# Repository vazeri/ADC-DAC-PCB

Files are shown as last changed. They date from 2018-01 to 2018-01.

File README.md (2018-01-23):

# Tarjeta para procesamiento de audio Analógico/Digital

Este proyecto se encuentra documentado y explicado a profundidad en el siguiente [articulo](https://github.com/vazeri/ADC-DAC-PCB/blob/master/pdf/ArticuloDAC.pdf)
 
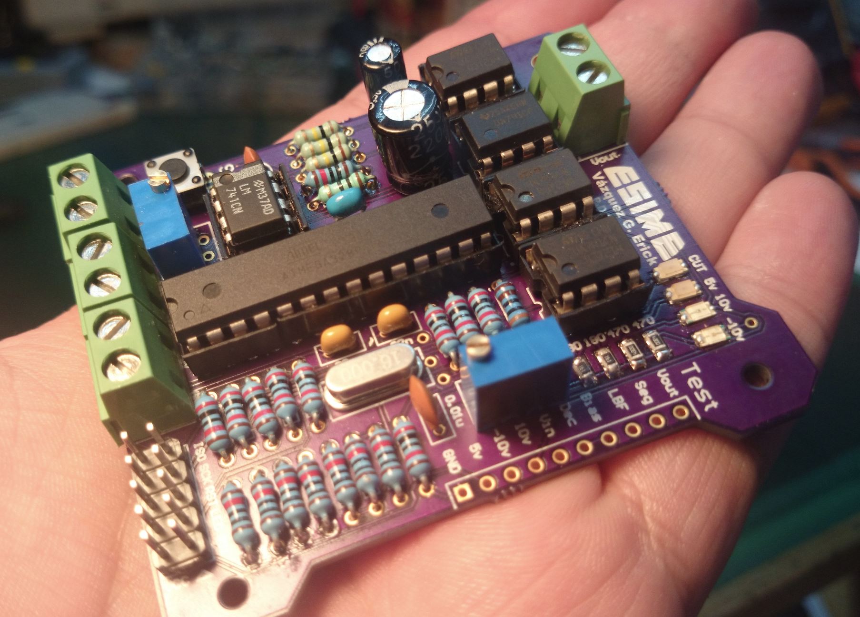
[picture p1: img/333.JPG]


El sonido y la computadora son inseparables, hoy en día en pocas aplicaciones se trabaja audio analógico y
casi todas editan por medio de software digitalmente, pero el sonido, en su origen continua siendo analógico...

La computadora, por lo tanto, tiene que contar con un dispositivo que transforme el audio analógico en digital
a este se llama tarjeta de audio de sonido que usualmente contiene un convertidor Analógico-Digital y un convertidor Digital-Analógico. En este reporte se describe el proceso de digitalizar una señal analógica de la voz humana, así como la serie de pasos a seguir para revertir este proceso

# ¿El proceso?



Es necesario tener un poco de teoría para comprender el proceso de el desarrollo teórico, esquemático y de PCB, para la implementación de una tarjeta de audio utilizando un microcontrolador de 8 bits ATMEGA328p

Los temas recomendados a estudiar antes de entrar de lleno a este proyecto son 

* Teorema de Nyquist
* Filtros de corriente directa
* Corrimientos de corriente directa
* Convertidor Analógico-Digital
* Arreglos Digital-Analógico R/2R 
* Filtros Pasa bajas
* Seguidor de tensión

En la carpeta PDF se anexan dos artículos en PDF para profundizar un poco sobre el tema, así como un [articulo](https://github.com/vazeri/ADC-DAC-PCB/blob/master/pdf/ArticuloDAC.pdf) escrito por mí para detallar el proceso de implementación del mismo 

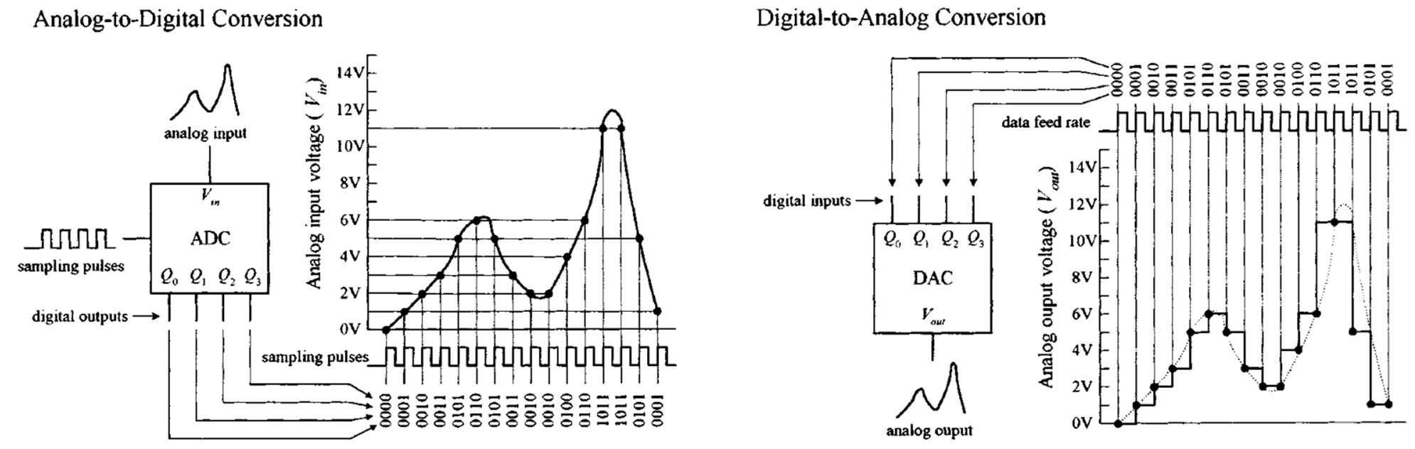
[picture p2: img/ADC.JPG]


# Esquemático

El esquemático fue diseñado el Altium Designer 14, en su versión de prueba, y se usa solo con fines educativos, 

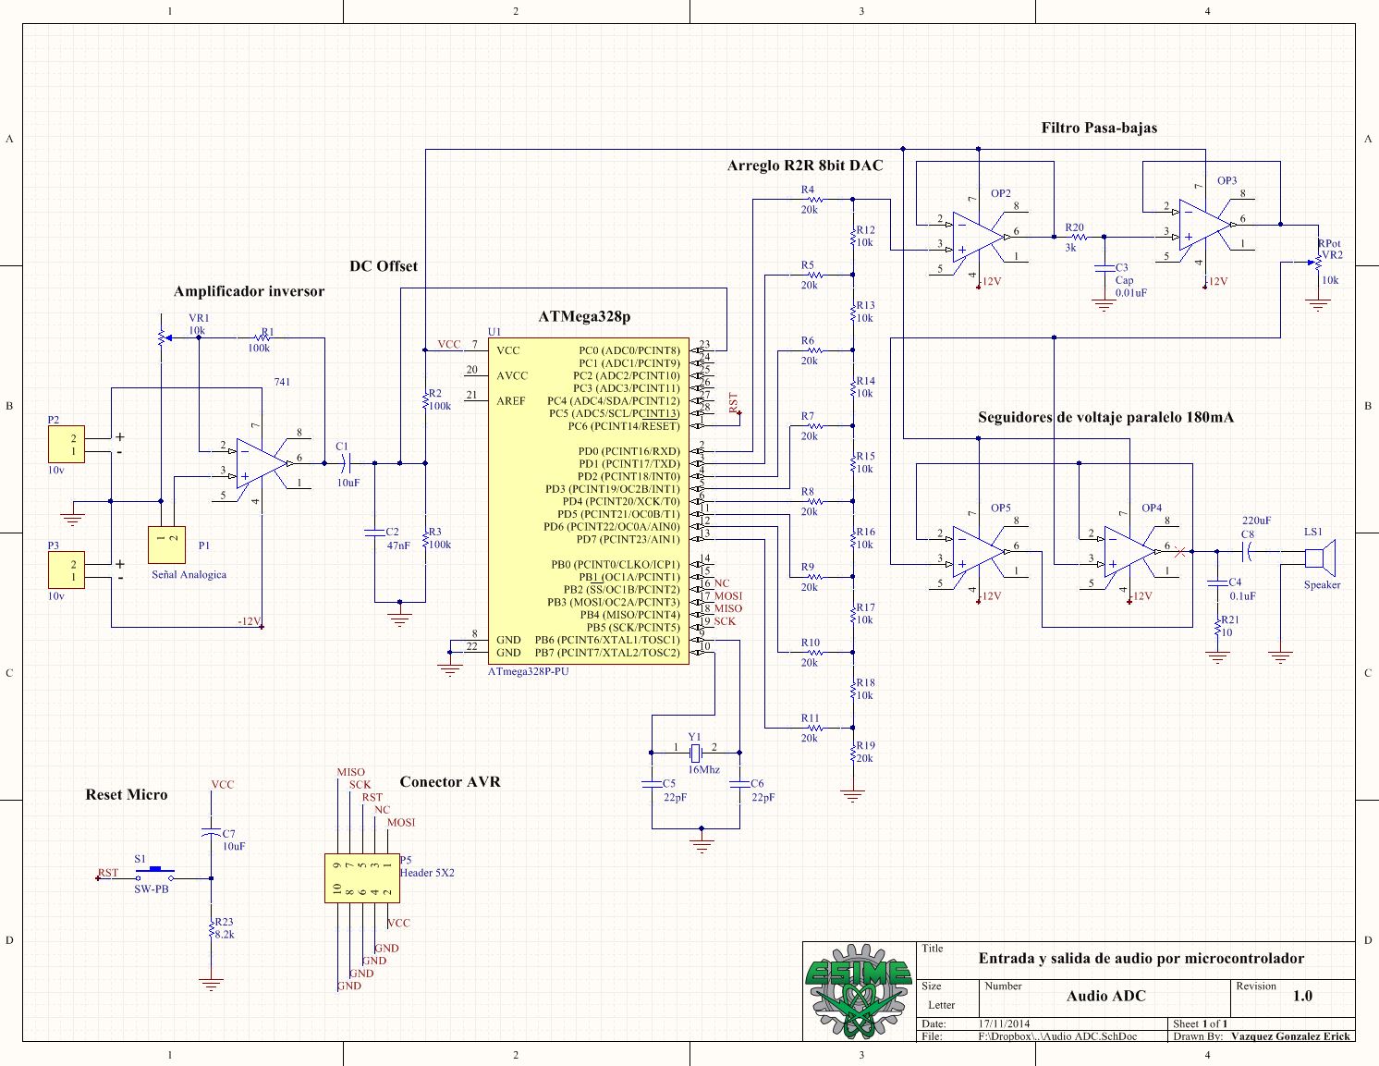
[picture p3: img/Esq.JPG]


# Placa de Circuito Impreso

El PCB de dos capas fue maquilado utilizando OSHPark con acabados ENIG oro

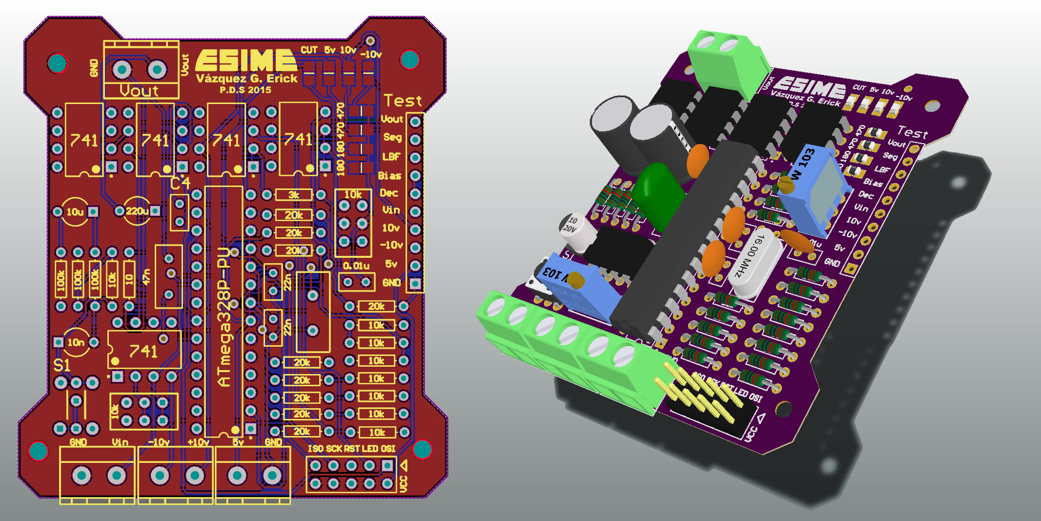
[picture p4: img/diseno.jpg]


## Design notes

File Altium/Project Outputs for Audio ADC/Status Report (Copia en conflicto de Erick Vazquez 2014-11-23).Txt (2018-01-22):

Output: NC Drill Files
Type  : NC Drill
From  : Project [Audio ADC.PrjPcb]
   Generated File[Audio ADC-RoundHoles.TXT]
   Generated File[Audio ADC-SquareHoles.TXT]
   Generated File[Audio ADC.DRL]
   Generated File[Audio ADC.LDP]
   Generated File[Audio ADC.DRR]

Files Generated   : 5
Documents Printed : 0

Finished Output Generation At 01:49:13 a.m. On 23/11/2014

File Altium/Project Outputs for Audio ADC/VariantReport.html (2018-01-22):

Altium customize

# Variant Report

Date | : | 07/11/2014
Time | : | 09:32:15 a.m.
Elapsed Time | : | 00:00:00

## Variations

Physical | Document | Parameter Name | Original Value
C1 | Audio ADC.SchDoc | | Fitted
| | Comment | Cap2
| | Description | Capacitor
| | Footprint | RAD-0.1
| | PackageDescription | Capacitor; 2 Leads
| | PackageReference | CAPR5-4X5
| | Published | 23-Sep-2002
| | Publisher | Altium Limited
| | Value | 10uF
C2 | Audio ADC.SchDoc | | Fitted
| | Comment | Cap
| | Description | Capacitor
| | Footprint | RAD-0.1
| | LatestRevisionDate | 17-Jul-2002
| | LatestRevisionNote | Re-released for DXP Platform.
| | PackageDescription | Radial Cap, Thru-Hole; 2 Leads; 0.3 in Pin Spacing
| | PackageReference | RAD-0.3
| | Published | 8-Jun-2000
| | Publisher | Altium Limited
| | Value | 47nF
C3 | Audio ADC.SchDoc | | Fitted
| | Comment | Cap
| | Description | Capacitor
| | Footprint | RAD-0.3
| | LatestRevisionDate | 17-Jul-2002
| | LatestRevisionNote | Re-released for DXP Platform.
| | PackageDescription | Radial Cap, Thru-Hole; 2 Leads; 0.3 in Pin Spacing
| | PackageReference | RAD-0.3
| | Published | 8-Jun-2000
| | Publisher | Altium Limited
| | Value | 0.01uF
C4 | Audio ADC.SchDoc | | Fitted
| | Comment | Cap
| | Description | Capacitor
| | Footprint | RAD-0.1
| | LatestRevisionDate | 17-Jul-2002
| | LatestRevisionNote | Re-released for DXP Platform.
| | PackageDescription | Radial Cap, Thru-Hole; 2 Leads; 0.3 in Pin Spacing
| | PackageReference | RAD-0.3
| | Published | 8-Jun-2000
| | Publisher | Altium Limited
| | Value | 0.1uF
C5 | Audio ADC.SchDoc | | Fitted
| | Comment | Cap
| | Description | Capacitor
| | Footprint | RAD-0.1
| | LatestRevisionDate | 17-Jul-2002
| | LatestRevisionNote | Re-released for DXP Platform.
| | PackageDescription | Radial Cap, Thru-Hole; 2 Leads; 0.3 in Pin Spacing
| | PackageReference | RAD-0.3
| | Published | 8-Jun-2000
| | Publisher | Altium Limited
| | Value | 22pF
C6 | Audio ADC.SchDoc | | Fitted
| | Comment | Cap
| | Description | Capacitor
| | Footprint | RAD-0.1
| | LatestRevisionDate | 17-Jul-2002
| | LatestRevisionNote | Re-released for DXP Platform.
| | PackageDescription | Radial Cap, Thru-Hole; 2 Leads; 0.3 in Pin Spacing
| | PackageReference | RAD-0.3
| | Published | 8-Jun-2000
| | Publisher | Altium Limited
| | Value | 22pF
C7 | Audio ADC.SchDoc | | Fitted
| | Comment | Cap2
| | Description | Capacitor
| | Footprint | CAPR5-4X5
| | PackageDescription | Capacitor; 2 Leads
| | PackageReference | CAPR5-4X5
| | Published | 23-Sep-2002
| | Publisher | Altium Limited
| | Value | 10uF
C8 | Audio ADC.SchDoc | | Fitted
| | Comment | Cap2
| | Description | Capacitor
| | Footprint | CAPR5-4X5
| | PackageDescription | Capacitor; 2 Leads
| | PackageReference | CAPR5-4X5
| | Published | 23-Sep-2002
| | Publisher | Altium Limited
| | Value | 220uF
LS1 | Audio ADC.SchDoc | | Fitted
| | Comment | Speaker
| | Description | Loudspeaker
| | Footprint | cONECTOR
| | LatestRevisionDate | 17-Jul-2002
| | LatestRevisionNote | Re-released for DXP Platform.
| | PackageReference | PIN2
| | Published | 24-Mar-1999
| | Publisher | Altium Limited
OP1 | Audio ADC.SchDoc | | Fitted
| | Comment | 741
| | ComponentLink1Description | Manufacturer Link
| | ComponentLink1URL | http://www.analog.com/
| | DatasheetVersion | REV. B
| | Description | FET Operational Amplifier
| | Footprint | DIP-8
| | LatestRevisionDate | 17-Jul-2002
| | LatestRevisionNote | Re-released for DXP Platform.
| | PackageDescription | Can; 8 Leads; Pin Circle Dia. 5.08 mm; Lead Dia. 0.53 mm (max)
| | PackageReference | H-08A
| | PackageVersion | 1990
| | Published | 8-Jun-2000
| | Publisher | Altium Limited
OP2 | Audio ADC.SchDoc | | Fitted
| | Comment | Op Amp
| | ComponentLink1Description | Manufacturer Link
| | ComponentLink1URL | http://www.analog.com/
| | DatasheetVersion | REV. B
| | Description | FET Operational Amplifier
| | Footprint | DIP-8
| | LatestRevisionDate | 17-Jul-2002
| | LatestRevisionNote | Re-released for DXP Platform.
| | PackageDescription | Can; 8 Leads; Pin Circle Dia. 5.08 mm; Lead Dia. 0.53 mm (max)
| | PackageReference | H-08A
| | PackageVersion | 1990
| | Published | 8-Jun-2000
| | Publisher | Altium Limited
OP3 | Audio ADC.SchDoc | | Fitted
| | Comment | Op Amp
| | ComponentLink1Description | Manufacturer Link
| | ComponentLink1URL | http://www.analog.com/
| | DatasheetVersion | REV. B
| | Description | FET Operational Amplifier
| | Footprint | DIP-8
| | LatestRevisionDate | 17-Jul-2002
| | LatestRevisionNote | Re-released for DXP Platform.
| | PackageDescription | Can; 8 Leads; Pin Circle Dia. 5.08 mm; Lead Dia. 0.53 mm (max)
| | PackageReference | H-08A
| | PackageVersion | 1990
| | Published | 8-Jun-2000
| | Publisher | Altium Limited
OP4 | Audio ADC.SchDoc | | Fitted
| | Comment | Op Amp
| | ComponentLink1Description | Manufacturer Link
| | ComponentLink1URL | http://www.analog.com/
| | DatasheetVersion | REV. B
| | Description | FET Operational Amplifier
| | Footprint | DIP-8
| | LatestRevisionDate | 17-Jul-2002
| | LatestRevisionNote | Re-released for DXP Platform.
| | PackageDescription | Can; 8 Leads; Pin Circle Dia. 5.08 mm; Lead Dia. 0.53 mm (max)
| | PackageReference | H-08A
| | PackageVersion | 1990
| | Published | 8-Jun-2000
| | Publisher | Altium Limited
OP5 | Audio ADC.SchDoc | | Fitted
| | Comment | Op Amp
| | ComponentLink1Description | Manufacturer Link
| | ComponentLink1URL | http://www.analog.com/
| | DatasheetVersion | REV. B
| | Description | FET Operational Amplifier
| | Footprint | DIP-8
| | LatestRevisionDate | 17-Jul-2002
| | LatestRevisionNote | Re-released for DXP Platform.
| | PackageDescription | Can; 8 Leads; Pin Circle Dia. 5.08 mm; Lead Dia. 0.53 mm (max)
| | PackageReference | H-08A
| | PackageVersion | 1990
| | Published | 8-Jun-2000
| | Publisher | Altium Limited
P1 | Audio ADC.SchDoc | | Fitted
| | Comment | Señal Analogica
| | Description | Header, 2-Pin
| | Footprint | cONECTOR
| | LatestRevisionDate | 17-Jul-2002
| | LatestRevisionNote | Re-released for DXP Platform.
| | Publisher | Altium Limited
P2 | Audio ADC.SchDoc | | Fitted
| | Comment | 12v
| | Description | Header, 2-Pin
| | Footprint | cONECTOR
| | LatestRevisionDate | 17-Jul-2002
| | LatestRevisionNote | Re-released for DXP Platform.
| | Publisher | Altium Limited
P3 | Audio ADC.SchDoc | | Fitted
| | Comment | 12v
| | Description | Header, 2-Pin
| | Footprint | MHDR1X2
| | LatestRevisionDate | 17-Jul-2002
| | LatestRevisionNote | Re-released for DXP Platform.
| | Publisher | Altium Limited
P5 | Audio ADC.SchDoc | | Fitted
| | Comment | Header 5X2
| | Description | Header, 5-Pin, Dual row
| | Footprint | HDR2X5
| | LatestRevisionDate | 17-Jul-2002
| | LatestRevisionNote | Re-released for DXP Platform.
| | Publisher | Altium Limited
R1 | Audio ADC.SchDoc | | Fitted
| | 100k | 100k
| | Comment | 100k
| | Description | Resistor
| | Footprint | AXIAL-0.3
| | LatestRevisionDate | 17-Jul-2002
| | LatestRevisionNote | Re-released for DXP Platform.
| | PackageDescription | Axial Device, Thru-Hole; 2 Leads; 0.3 in Pin Spacing
| | PackageReference | AXIAL-0.3
| | Published | 8-Jun-2000
| | Publisher | Altium Limited
R2 | Audio ADC.SchDoc | | Fitted
| | Comment | 100k
| | Description | Resistor
| | Footprint | AXIAL-0.3
| | LatestRevisionDate | 17-Jul-2002
| | LatestRevisionNote | Re-released for DXP Platform.
| | PackageDescription | Axial Device, Thru-Hole; 2 Leads; 0.3 in Pin Spacing
| | PackageReference | AXIAL-0.3
| | Published | 8-Jun-2000
| | Publisher | Altium Limited
| | Value | 100k
R3 | Audio ADC.SchDoc | | Fitted
| | Comment | 100k
| | Description | Resistor
| | Footprint | AXIAL-0.3
| | LatestRevisionDate | 17-Jul-2002
| | LatestRevisionNote | Re-released for DXP Platform.
| | PackageDescription | Axial Device, Thru-Hole; 2 Leads; 0.3 in Pin Spacing
| | PackageReference | AXIAL-0.3
| | Published | 8-Jun-2000
| | Publisher | Altium Limited
| | Value | 100k
R4 | Audio ADC.SchDoc | | Fitted
| | Comment | 20k
| | Description | Resistor
| | Footprint | AXIAL-0.3
| | LatestRevisionDate | 17-Jul-2002
| | LatestRevisionNote | Re-released for DXP Platform.
| | PackageDescription | Axial Device, Thru-Hole; 2 Leads; 0.3 in Pin Spacing
| | PackageReference | AXIAL-0.3
| | Published | 8-Jun-2000
| | Publisher | Altium Limited
| | Value | 1K
R5 | Audio ADC.SchDoc | | Fitted
| | Comment | 20k
| | Description | Resistor
| | Footprint | AXIAL-0.3
| | LatestRevisionDate | 17-Jul-2002
| | LatestRevisionNote | Re-released for DXP Platform.
| | PackageDescription | Axial Device, Thru-Hole; 2 Leads; 0.3 in Pin Spacing
| | PackageReference | AXIAL-0.3
| | Published | 8-Jun-2000
| | Publisher | Altium Limited
| | Value | 1K
R6 | Audio ADC.SchDoc | | Fitted
| | Comment | 20k
| | Description | Resistor
| | Footprint | AXIAL-0.3
| | LatestRevisionDate | 17-Jul-2002
| | LatestRevisionNote | Re-released for DXP Platform.
| | PackageDescription | Axial Device, Thru-Hole; 2 Leads; 0.3 in Pin Spacing
| | PackageReference | AXIAL-0.3
| | Published | 8-Jun-2000
| | Publisher | Altium Limited
| | Value | 1K
R7 | Audio ADC.SchDoc | | Fitted
| | Comment | 20k
| | Description | Resistor
| | Footprint | AXIAL-0.3
| | LatestRevisionDate | 17-Jul-2002
| | LatestRevisionNote | Re-released for DXP Platform.
| | PackageDescription | Axial Device, Thru-Hole; 2 Leads; 0.3 in Pin Spacing
| | PackageReference | AXIAL-0.3
| | Published | 8-Jun-2000
| | Publisher | Altium Limited
| | Value | 1K
R8 | Audio ADC.SchDoc | | Fitted
| | Comment | 20k
| | Description | Resistor
| | Footprint | AXIAL-0.3
| | LatestRevisionDate | 17-Jul-2002
| | LatestRevisionNote | Re-released for DXP Platform.
| | PackageDescription | Axial Device, Thru-Hole; 2 Leads; 0.3 in Pin Spacing
| | PackageReference | AXIAL-0.3
| | Published | 8-Jun-2000
| | Publisher | Altium Limited
| | Value | 1K
R9 | Audio ADC.SchDoc | | Fitted
| | Comment | 20k
| | Description | Resistor
| | Footprint | AXIAL-0.3
| | LatestRevisionDate | 17-Jul-2002
| | LatestRevisionNote | Re-released for DXP Platform.
| | PackageDescription | Axial Device, Thru-Hole; 2 Leads; 0.3 in Pin Spacing
| | PackageReference | AXIAL-0.3
| | Published | 8-Jun-2000
| | Publisher | Altium Limited
| | Value | 1K
R10 | Audio ADC.SchDoc | | Fitted
| | Comment | 20k
| | Description | Resistor
| | Footprint | AXIAL-0.3
| | LatestRevisionDate | 17-Jul-2002
| | LatestRevisionNote | Re-released for DXP Platform.
| | PackageDescription | Axial Device, Thru-Hole; 2 Leads; 0.3 in Pin Spacing
| | PackageReference | AXIAL-0.3
| | Published | 8-Jun-2000
| | Publisher | Altium Limited
| | Value | 1K
R11 | Audio ADC.SchDoc | | Fitted
| | Comment | 20k
| | Description | Resistor
| | Footprint | AXIAL-0.3
| | LatestRevisionDate | 17-Jul-2002
| | LatestRevisionNote | Re-released for DXP Platform.
| | PackageDescription | Axial Device, Thru-Hole; 2 Leads; 0.3 in Pin Spacing
| | PackageReference | AXIAL-0.3
| | Published | 8-Jun-2000
| | Publisher | Altium Limited
| | Value | 1K
R12 | Audio ADC.SchDoc | | Fitted
| | Comment | 10k
| | Description | Resistor
| | Footprint | AXIAL-0.3
| | LatestRevisionDate | 17-Jul-2002
| | LatestRevisionNote | Re-released for DXP Platform.
| | PackageDescription | Axial Device, Thru-Hole; 2 Leads; 0.3 in Pin Spacing
| | PackageReference | AXIAL-0.3
| | Published | 8-Jun-2000
| | Publisher | Altium Limited
| | Value | 1K
R13 | Audio ADC.SchDoc | | Fitted
| | Comment | 10k
| | Description | Resistor
| | Footprint | AXIAL-0.3
| | LatestRevisionDate | 17-Jul-2002
| | LatestRevisionNote | Re-released for DXP Platform.
| | PackageDescription | Axial Device, Thru-Hole; 2 Leads; 0.3 in Pin Spacing
| | PackageReference | AXIAL-0.3
| | Published | 8-Jun-2000
| | Publisher | Altium Limited
| | Value | 1K
R14 | Audio ADC.SchDoc | | Fitted
| | Comment | 10k
| | Description | Resistor
| | Footprint | AXIAL-0.3
| | LatestRevisionDate | 17-Jul-2002
| | LatestRevisionNote | Re-released for DXP Platform.
| | PackageDescription | Axial Device, Thru-Hole; 2 Leads; 0.3 in Pin Spacing
| | PackageReference | AXIAL-0.3
| | Published | 8-Jun-2000
| | Publisher | Altium Limited
| | Value | 1K
R15 | Audio ADC.SchDoc | | Fitted
| | Comment | 10k
| | Description | Resistor
| | Footprint | AXIAL-0.3
| | LatestRevisionDate | 17-Jul-2002
| | LatestRevisionNote | Re-released for DXP Platform.
| | PackageDescription | Axial Device, Thru-Hole; 2 Leads; 0.3 in Pin Spacing
| | PackageReference | AXIAL-0.3
| | Published | 8-Jun-2000
| | Publisher | Altium Limited
| | Value | 1K
R16 | Audio ADC.SchDoc | | Fitted
| | Comment | 10k
| | Description | Resistor
| | Footprint | AXIAL-0.3
| | LatestRevisionDate | 17-Jul-2002
| | LatestRevisionNote | Re-released for DXP Platform.
| | PackageDescription | Axial Device, Thru-Hole; 2 Leads; 0.3 in Pin Spacing
| | PackageReference | AXIAL-0.3
| | Published | 8-Jun-2000
| | Publisher | Altium Limited
| | Value | 1K
R17 | Audio ADC.SchDoc | | Fitted
| | Comment | 10k
| | Description | Resistor
| | Footprint | AXIAL-0.3
| | LatestRevisionDate | 17-Jul-2002
| | LatestRevisionNote | Re-released for DXP Platform.
| | PackageDescription | Axial Device, Thru-Hole; 2 Leads; 0.3 in Pin Spacing
| | PackageReference | AXIAL-0.3
| | Published | 8-Jun-2000
| | Publisher | Altium Limited
| | Value | 1K
R18 | Audio ADC.SchDoc | | Fitted
| | Comment | 10k
| | Description | Resistor
| | Footprint | AXIAL-0.3
| | LatestRevisionDate | 17-Jul-2002
| | LatestRevisionNote | Re-released for DXP Platform.
| | PackageDescription | Axial Device, Thru-Hole; 2 Leads; 0.3 in Pin Spacing
| | PackageReference | AXIAL-0.3
| | Published | 8-Jun-2000
| | Publisher | Altium Limited
| | Value | 1K
R19 | Audio ADC.SchDoc | | Fitted
| | Comment | 20k
| | Description | Resistor
| | Footprint | AXIAL-0.3
| | LatestRevisionDate | 17-Jul-2002
| | LatestRevisionNote | Re-released for DXP Platform.
| | PackageDescription | Axial Device, Thru-Hole; 2 Leads; 0.3 in Pin Spacing
| | PackageReference | AXIAL-0.3
| | Published | 8-Jun-2000
| | Publisher | Altium Limited
| | Value | 1K
R20 | Audio ADC.SchDoc | | Fitted
| | Comment | 3k
| | Description | Resistor
| | Footprint | AXIAL-0.3
| | LatestRevisionDate | 17-Jul-2002
| | LatestRevisionNote | Re-released for DXP Platform.
| | PackageDescription | Axial Device, Thru-Hole; 2 Leads; 0.3 in Pin Spacing
| | PackageReference | AXIAL-0.3
| | Published | 8-Jun-2000
| | Publisher | Altium Limited
| | Value | 1K
R21 | Audio ADC.SchDoc | | Fitted
| | Comment | 10
| | Description | Resistor
| | Footprint | AXIAL-0.3
| | LatestRevisionDate | 17-Jul-2002
| | LatestRevisionNote | Re-released for DXP Platform.
| | PackageDescription | Axial Device, Thru-Hole; 2 Leads; 0.3 in Pin Spacing
| | PackageReference | AXIAL-0.3
| | Published | 8-Jun-2000
| | Publisher | Altium Limited
| | Value | 1K
R23 | Audio ADC.SchDoc | | Fitted
| | Comment | 8.2k
| | Description | Resistor
| | Footprint | AXIAL-0.3
| | LatestRevisionDate | 17-Jul-2002
| | LatestRevisionNote | Re-released for DXP Platform.
| | PackageDescription | Axial Device, Thru-Hole; 2 Leads; 0.3 in Pin Spacing
| | PackageReference | AXIAL-0.3
| | Published | 8-Jun-2000
| | Publisher | Altium Limited
| | Value | 1K
S1 | Audio ADC.SchDoc | | Fitted
| | Comment | SW-PB
| | Description | Switch
| | Footprint | SPST-2
| | LatestRevisionDate | 17-Jul-2002
| | LatestRevisionNote | Re-released for DXP Platform.
| | PackageDescription | Switch; 2 Leads
| | PackageReference | SPST-2
| | Published | 24-Mar-1999
| | Publisher | Altium Limited
U1 | Audio ADC.SchDoc | | Fitted
| | Comment | ATmega328P-PU
| | ComponentLink1Description | Manufacturer Link
| | ComponentLink1URL | http://www.atmel.com/products/avr/default.asp?
| | ComponentLink2Description | ATmega48A/48PA/88A/88PA/168A/168PA/328/328P Datasheet
| | ComponentLink2URL | http://www.atmel.com/dyn/resources/prod_documents/8271.pdf
| | ComponentLink3Description | ATmega48A/48PA/88A/88PA/168A/168PA/328/328P Summary
| | ComponentLink3URL | http://www.atmel.com/dyn/resources/prod_documents/8271S.pdf
| | ComponentLink4Description | Atmel.com Home
| | ComponentLink4URL | http://www.atmel.com
| | DatasheetVersion | revA, Jan-2010
| | Description | 8-bit AVR Microcontroller, 32KB Flash, 1KB EEPROM, 2KB SRAM, 28-pin PDIP, Industrial Grade (-40°C to 85°C)
| | Footprint | 28P3
| | PackageDescription | 28-lead (0.300"/7.62mm Wide) Plastic Dual Inline Package (PDIP)
| | PackageReference | 28P3
| | PackageVersion | revB, Sep-2001
| | Published | 1-Apr-2010
| | Publisher | Altium Limited
| | Supplier 1 | Digi-Key
| | Supplier 2 | Farnell
| | Supplier 3 | Mouser
| | Supplier Part Number 1 | ATMEGA328P-PU-ND
| | Supplier Part Number 2 | 1715487
| | Supplier Part Number 3 | 556-ATMEGA328P-PU
VR1 | Audio ADC.SchDoc | | Fitted
| | Comment | RPot
| | Description | Potentiometer
| | Footprint | VR5
| | LatestRevisionDate | 17-Jul-2002
| | LatestRevisionNote | Re-released for DXP Platform.
| | PackageDescription | Variable Resistor, Thru-Hole; 3 Leads
| | PackageReference | VR5
| | Published | 8-Jun-2000
| | Publisher | Altium Limited
| | Set Position | 0.5
| | Sim Note | Enter the Resistance value and the set point into parameter fields.
| | Value | 10k
VR2 | Audio ADC.SchDoc | | Fitted
| | Comment | RPot
| | Description | Potentiometer
| | Footprint | VR5
| | LatestRevisionDate | 17-Jul-2002
| | LatestRevisionNote | Re-released for DXP Platform.
| | PackageDescription | Variable Resistor, Thru-Hole; 3 Leads
| | PackageReference | VR5
| | Published | 8-Jun-2000
| | Publisher | Altium Limited
| | Set Position | 0.5
| | Sim Note | Enter the Resistance value and the set point into parameter fields.
| | Value | 10k
Y1 | Audio ADC.SchDoc | | Fitted
| | Comment | 16Mhz
| | Description | Crystal Oscillator
| | Footprint | RAD-0.4
| | LatestRevisionDate | 17-Jul-2002
| | LatestRevisionNote | Re-released for DXP Platform.
| | PackageDescription | Crystal, Thru-Hole; 2 Leads; Body 3.1 x 8.2 mm (Dia.xH)
| | PackageReference | R38
| | Published | 8-Jun-2000
| | Publisher | Altium Limited

Back to top

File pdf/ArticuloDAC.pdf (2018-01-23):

Procesamiento digital de senales ˜ Erick Vazquez ´

# Tarjeta de audio de procesamiento de voz dígital

Vazquez Gonz ´ | alez Erick, ESIME Zacatenco ´

Abstract
El sonido y la computadora son inseparables, hoy en día en pocas aplicaciones se trabaja audio analogico y ´ casi todas editan usando software y computadoras. Pero el sonido, en su origen continua siendo analogico. ´ La computadora, por lo tanto, tiene que contar con un dispositivo que transforme el audio analogico en digital ´ a este se llama tarjeta de audio o de sonido. En este reporte se describe el proceso de digitalizar una senal ˜ analogica de la voz humana, asi como la serie de pasos a seguir para lograr este proceso ´
Keywords
Muestreo — Cuantizacion — ADC — Acondicionamiento de senal — Microcontrolador — Nyquist ˜

1
Ingeniería en Comunicaciones y Electronica, ESIME Zacatenco, M ´ | exico DF, 2014 ´
*Datos del Autor: gzerox@gmail.com, 55 2526 7770

### Contents

Introduccion | 1
1 | Marco Teorico ´ | 2

Capacitor Bypass

2 | Disenõ | 5
Simulacion de se ´ | nal continua ˜ | • Simulacion de se ´ | nal discreta ˜

Muestreo a 8kHz en puerto A0 • Muestreo a 8kHz en A0 con salida a DAC de 8 bits • Muestreo a 38.5kHz por el puerto A0 • Muestreo a 38.5kHz en puerto A0 con salida a DAC de 8 bits

3 | Conclusiones y Observaciones | 8
4 | Bibliografía y referencias | 9

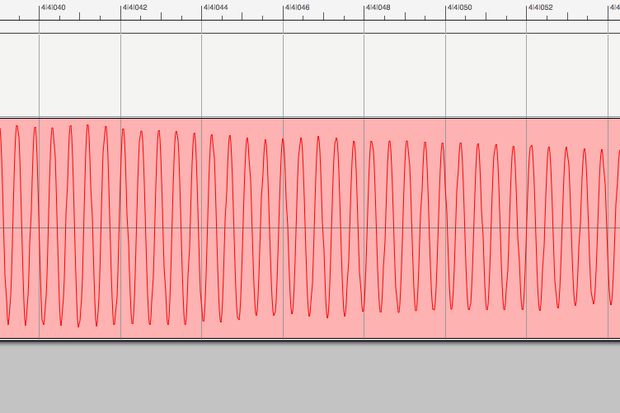
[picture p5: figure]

Figure 1. Senal de audio amplificada en tiempo ˜

### Introduccion´

Si alguna vez ha grabado audio en su computadora, es muy probable que haya visto una forma de onda que varía dependiendo de la intensidad del sonido grabado, si amplificamos esta senal en el tiempo (figura 1) podemos observar que esta ˜ senal est ˜ a formada por cientos de miles de oscilaciones que ´ van y vienen, a esto le llamamos senal de audio y cuando ˜
tratamos con senales de audio en la electr ˜ | onica, esas oscila- ´
ciones representan voltajes en el tiempo. Una senal de audio ˜ típica oscila alrededor de 0v esto es normal para senales de ˜ audio, la amplitud de una senal de audio puede ser de 2V, sin ˜ embargo esto significa que alcanza su maximo voltaje en 2V y ´ su mínimo en -2v esto es un problema, que debemos resolver, es decir, debemos acondicionar nuestra senal para poder ser ˜ leida por el microcontrolador

### Objetivos

### 0.1 Objetivo General

Diseno simulaci ˜ | on y construcci ´ | on de un circuito que permita ´
acondicionar una senal de voz para poder convertirla en una ˜ senal digital, por medio de un microcontrolador ˜

Tarjeta de audio de procesamiento de voz dígital — 2/9

### 0.2 Nivel usuario

- Obtener cualquier una senal de voz ˜
- Convertirla en una senal digital ˜
- Reproducir el sonido digital por medio de altavoces

### 0.3 Nivel tecnico

- Aplicar el teorema de Nyquist
- Simular la senal en MATLAB (Generar tonos de prueba) ˜
- Identificar cada uno de los circuitos del sistema
- Probar cada circuito independientemente
- Integracion del sistema ´

### 0.4 Nivel sistema

- Identificar cada uno de los sistemas que haran funcionar ´ a nuestro circuito
- Amplificar la senal a 5v ˜
- Aplicar un Offset de DC para que el microcontrolador pueda leer 2⁸ valores (256)
- Canalizar por un puerto del microcontrolador la senal ˜ digitalizada
- Convertir la senal discreta en continua ˜
- Remover ruidos de la senal a lo largo del sistema ˜
- Filtrar frecuencias no deseadas
- Amplificar la corriente de salida del sistema

### 1. Marco Teorico ´

### 1.1 Teoría de muestreo

Nyquist afirmaba que una senal Analogica puede ser recon- ˜ struida, sin error, de muestras tomadas en intervalos iguales de tiempo, la razon de muestreo debe ser igual o mayor al ´ doble de su ancho de banda de la senal Analogica ˜
La teoría de muestro define que para que una senal de ˜ ancho de banda limitado la frecuencia de muestreo FM debe ser mayor que 2 veces su ancho de banda BW medido en Hertz
Fm=2*BW | (1)

Si nuestra senal a ser digitalizada es la voz entonces el ˜ ancho de banda de la voz es de 4000Hz su frecuencia de muestreo será 8000Hz, equivalente a 8000 muestras por segundo 1/8000 entonces la razon de muestreo de la voz debe ´ ser de al menos 8000Hz para que pueda regenerarse sin error. 2∗BW es la frecuencia de Nyquist o frecuencia de muestreo El oído humano solo puede detectar sonidos en el rango de 20Hz a 20kHz, de acuerdo a la teoría de muestreo debemos muestrear la senal al menos a 40Khz para reconstruir una ˜
senal de sonido aceptable al o ˜ | ído humano, el sonido digital-
izado se compone de muestras de sonido captadas a diferentes frecuencias. Cuantas mas muestras de sonido se capten por ´ segundo, mayor sera su calidad, los DVD utilizan 48 kHz, los ´ CD de audio usan una frecuencia de muestreo de 44,1 kHz, la Radio FM 22kHz, y las voces de la redes telefonicas usan 8 ´ kHz.
La frecuencia de muestreo que seleccione dependera de la ´ naturaleza del sonido.

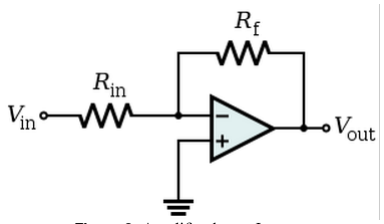
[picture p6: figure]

Figure 2. Amplificador no Inversor

### 1.2 Tamano de muestra ˜

El tamano de la muestra de sonido o Taza de bits, (bit rate) ˜ determina su margen dinamico. viene definido por la siguiente ´ formula

2

N
(2)

Donde N es el numero de bits, el sonido de 8 bits entonces, ´ suministra 255 valores posibles, mientras que el de 16 bits permite mas de 65.000 valores posibles. ´
Las computadoras por lo general reproducen un sonido de
16 bits para la musica que permite reproducir m ´ | usica suave ´
como de musica fuerte, por ejemplo, la orquestal. Para la voz ´
o la musica de volumen m ´ | as constante, telefon ´ | ía fija, el sonido
de 8 bits suele dar buenos resultados.
Si necesita reducir tamano de un archivo multimedia, ˜ puede reducir el tamano de la muestra de 16 a 8 bits. Con ˜
esto el tamano del archivo se reduce a la mitad, pero tambi ˜ | en´
”empeora” la calidad del audio.
El oído humano no es capaz de percibir la diferencia entre tamanos de muestra mayores a 16 bits, sin embargo existen ˜ dispositivos y convertidores de estos valores.

### 1.3 Amplificador no Inversor

El amplificador es la primera parte del circuito, los transductores manejan amplitudes alrededor de 200mV , por lo que requerimos incrementar la amplitud a un valor cercano a 2.5v sin excederlo la otra funcion del amplificador es proteger la ´ fuente del audio, (lo que sea que genere el audio, microfono, ´
telefono, pc, radio, etc. . . ) del resto del circuito, la se ´ | nal am- ˜
plificada requerira toda la corriente del amplificador , as ´ | í que
cualquier carga puesta despues en el acto no ser ´ | a “sentida” por ´
la fuente, utilizaremos nuestros OP AMPS en configuracion´ no inversora, adicionalmente la alta impedancia de nuestro AmpOp protegera al dispositivo emisor de cualquier falla en ´ nuestro sistema que pueda llegar a presentarse Alimentaremos nuestros OP AMPS con +-10v debido a
que la senal no ser ˜ | a amplificada nunca m ´ | as all ´ | a de 2.5v ´
La siguiente ecuacion describe la relaci ´ | on entre ampli- ´
tudes antes y despues del amplificador no inversor ´

Vout = Vin ∗ (1+

R2
R1
) | (3)

Tarjeta de audio de procesamiento de voz dígital — 3/9

Donde R2 es la resistencia de retroalimentacion, entre la ´ salida y la terminal no inversora, R1 es la resistencia a tierra, Vout es la amplitud de la senal de salida, (de la salida del ˜ amplificador) y Vin es la amplitud de la senal de entrada (La ˜ entrada del amplificador).
En nuestro caso R2 sera 100k y R1 un potenci ´ | ometro de ´
10k, girando el potenciometro , podremos pasar de 0 a 10k. ´
Cuando el Potenciometro est ´ | a proporcionando su resisten- ´
cia maxima de 10k la relaci ´ | on de entrada salida ser ´ | a:´

Vout = Vin ∗ (1+

100kOhm
10kOhm
) = 11 | (4)
la senal que viene del micr ˜ | ofono con una amplitud de ´
200mv (que es bastante fuerte para un microfono) ser ´ | a ampli- ´
ficada a:
200mv ∗ 11 = 2200mV = 2.2v | (5)

Este es el rango adecuado que queremos (Amplitud cerca de 2.5v sin pasarnos)
Si giramos el potenciometro hasta la mitad obtendremos ´ una resistencia de 5kOhms en donde podemos calcular nuevamente la relacion de entrada y salida ´

Vout = Vin ∗ (1+

100kOhm
5kOhm
) = 21 | (6)

La amplitud se multiplicara por 21, esto es demasiado para la senal de 200mV ˜

200mv ∗ 21 = 4200mV = 4.2v >> 2.2v | (7)

Sin embargo esta amplificacion seria perfecta para una ´ senal de 100mv ˜

100mv ∗ 21 = 2100mV = 2.1v | (8)
Girar el potenciometro m ´ | as all ´ | a mantendr ´ | a decrementando ´
la resistencia de R1 e incrementara la amplificacion tambi ´ | en´
llamada ganancia , de este amplificador teoricamente hasta ´ el infinito ,ajustando el potenciometro podemos ajustar la ´ ganancia del amplificador para acomodarla a la sensibilidad del microfono mientras mantenemos un rango adecuado para ´ que ADC del microcontrolador pueda manejar

### 1.3.1 Capacitor Bypass

El capacitor bypass es un capacitor electrolítico conectado directamente a la fuente de voltaje y a tierra, esto permite que nuestra componente de corriente alterna sea filtrada, el capacitor actua como una reserva de corriente y ayuda a rel- ´ lenar cualquier corte que llegue a haber en nuestro voltaje
Vcc liberandolo cuando el voltaje llegue a caer, el tama ´ | no del ˜
capacitor determina que tan grande puede ser ese ”hueco” que se debe rellenar, entra mas grande el valor, mayor es el hueco ´ que puede rellenar, un tamano com ˜ un utilizado es .1uF, sin ´ embargo el valor preciso del capacitor no es importante, sin embargo altas frecuencias requieren capacitores de menores valores, en nuestro diseno utilizaremos un capacitor de 47nF ˜

### 1.4 Filtro de CD

A la salida de nuestro primer OPAMP utilizaremos un capacitor electrolítico de 10uF a 12 o 15v en serie, esto para filtrar la componente de CD que pueda generar ruido en nuestro
sistema y dejar una senal senoidal lo m ˜ | as fina posible, la parte ´
positiva del capacitor va a la salida de nuestro OPAMP y la negativa al resto del circuito

### 1.5 Offset de CD

Los micro controladores solo pueden medir voltajes entre 0 y 5v, si medimos los voltajes negativos el micro controlador este
solo leera 0v y terminar ´ | íamos cortando el semiciclo negativo
de la senal , sin embargo, es posible amplificar y aplicar un ˜
offset a esta senal de audio para que est ˜ | e colocadas entre este ´
rango, idealmente la colocaremos en 2.5v para que su voltaje mínimo sea 0v y su maximo 5v ´
Con la intencion de que el micro controlador sea capaz ´ de leer los voltajes de 0 a 5v es necesario desplazar nuestra senal del origen a un voltaje promedio de 2.5v, esto le permite ˜ al microcontrolador procesar los valores de 0 a 256 y de esta
manera el voltaje de CD sobre el cual estara montada la se ´ | nal ˜
senoidal, sera 2.5V lo significa que la se ´ | nal estar ˜ | a desplazada ´
hacia arriba 2.5v

V max = V central −Amplitud = 2.5v+2.5v = 5v (9)

V min =V central −Amplitud = −2.5v+2.5v = 0v (10)

La siguiente senal esta amplificada sin embargo a ˜ | un se ´
encuentra acoplada en 0v oscilando entre -2.5v y 2.5v por lo que para corregir esto tendremos que aplicar un Offset de CD, que significa cambiar el voltaje promedio de la onda con su voltaje central en 2.5v en lugar de 0v, es decir la senal ˜ senoidal oscilara alrededor de 2.5v y no de 0v, esta senal est ˜ á preparada para ser recibida por el puerto analogico de nuestro ´ micro controlador
Para lograr esto el circuito tendra 2 componentes prin- ´ cipales, un divisor de voltaje y un capacitor bypass, para el divisor de voltaje la formula es: ´

Vout =

R1
R1+R2
∗V f uente | (11)

se compone de 2 resistencias de 100kOhms serie conectadas a una fuente de alimentacion externa de 5v, que originalmente ´ alimenta al microcontrolador, Con la intencion de que el micro ´ controlador sea capaz de leer los voltajes de 0 a 5v es necesario desplazar nuestra senal del origen a un voltaje promedio de ˜

Tarjeta de audio de procesamiento de voz dígital — 4/9

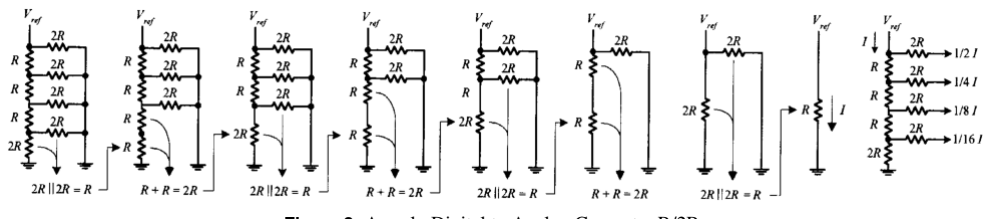
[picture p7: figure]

Figure 3. Arreglo Digital to Analog Converter R/2R

2.5v, esto le permite al microcontrolador procesar los valores de 0 a 256 y de esta manera el voltaje de CD sobre el cual
estara montada la se ´ | nal senoidal, ˜
El capacitor se colocara en paralelo hacia tierra m tambien´ se le conoce como capacitor bypass y permite filtrar a tierra el ruido de Corriente alterna inherente de cualquier circuito sera de 47nF ´

Vout =

100kOhm
100kOhm+100kOhm
∗ 5v = 2.5v | (12)

### 1.6 Convertidor Analogico-Digital ´

Un conversor, (o convertidor) de senal anal ˜ | ogica a digital, o ´
ADC del ingles (”Analog-to-Digital Converter”) es un dis- ´
positivo electronico capaz de convertir una se ´ | nal anal ˜ | ogica ´
de voltaje en una senal digital con un valor binario. Se uti- ˜ liza en equipos electronicos como computadora, grabadores ´ de sonido y de vídeo, y equipos de telecomunicaciones. La
senal anal ˜ | ogica, que var ´ | ía de forma continua en el tiempo, se
conecta a la entrada del dispositivo y se somete a un muestreo
a una velocidad fija, obteniendose as ´ | í una senal digital a la ˜
salida
Nuestro microcontrolador ATMEGA328P tiene 3 puertos dedicados con ADCs de una resolucion de 10 bits, es decir ´ hasta 1024 valores, la frecuencia de muestrea por default de este microcontrolador es de 8kHz, pero es posible modificar este valor utilizando los comandos proporcionados en la hoja de datos del fabricante

### 1.7 Arreglo R/2R DAC

Debido a que nuestro microcontrolador no tiene las capacidades de salida analogicas tenemos que usar un DAC (Digital ´ to Analog Converter) para convertir nuestros datos digitales (Bytes/Numeros/Enteros) en una forma de onda Analogica ´
(tension oscilante) una forma econ ´ | omica y sencilla de hacer ´
esto es utilizar una escalera R/2R, Esencialmente toma la salida digital de 0v a 5v los pesa y los suma para producir un voltaje entre 0v y 5v se puede pensar de este arreglo como un divisor de voltaje de multiples niveles ´
En este caso particular utilizaremos un ADC R2R de 8 bit, esto significa que puede producir 2

8
(256) diferentes voltajes
entre 0v y 5v, y los conectaremos a los pines 0-7 de un puerto en nuestro microcontrolador

Un arreglo de este tipo utiliza una escalera de resistencias utilizando solo 2 valores R y 2R la figura muestra un arreglo simple de 4 bits , por ahora asumiremos que switches logicos ´ controlaran las entradas, la corriente siempre es la misma no importa si se activa un switch o varios , la corriente fluye a tierra si el switch se apaga, , sin embargo si este prende fluira hacia una tierra virtual de la terminal no inversora de ´
un OPAMP convertira la se ´ | nal no inversora en 0v v ˜ | ía retroali-
mentacion negativa ´

### 1.8 Filtro Pasa Bajas

El proposito del filtro pasa bajas es suavizar la salida del DAC ´ con la intencion de reducir el ruido, usando un filtro se pueden ´ reducir los pasos, de nuestra senal digital, , para lograr esto ˜ se requiere una resistencia y capacitor en serie hacia tierra la
senal que pase entre estos dos ser ˜ | a filtrada , para calcular los ´
valores de estos se puede utilizar la siguiente formula

Fc =

1
2 ∗ pi ∗R∗C

(13)

El teorema de Nyquist establece que para una senal con ˜ una sampling de x Hz la frecuencia mas alta producida debe ´ ser 2 veces ese valor, debemos establecer nuestra frecuencia de corte en 2*B
Si tuviesemos una frecuencia de corte de 40khz (standard ´ para audio musical) entonces la frecuencia maxima que pode- ´ mos reproducir es de 20khz (el límite superior del espectro audible), y la frecuencia de corte del filtro pasa bajas debe estar alrededor de los 20khz
Principalmente estaremos digitalizando voz, por lo que para evitar el ruido en el sistema, debemos limitar nuestro sistema para poder reducir los tonos agudos por lo que calcularemos nuestro filtro a poco mas de 8khz ´
Para una frecuencia de corte de 8000hz y una resistencia de 1.5kohms

8000Hz =

1
2 ∗ pi ∗R∗ 0.01uF

(14)

R = 2kOhm | (15)

Tarjeta de audio de procesamiento de voz dígital — 5/9

Fc =

1
2 ∗ pi ∗ 2kOhm∗ 0.01uF

= 7957.75Hz (16)

Estos valores nos ayudaran a elegir los componentes adecuados para filtrar nuestra senal y remover ruido no deseado ˜

### 1.9 Seguidor de Tension´

Usualmente utilizamos los AMPOPS para amplificar voltaje sin embargo es posible utilizarlos para incrementar la corriente de la senal paras que pueda manejar una carga (Altavoz) ˜ en esta etapa del circuito acoplamos nuestros LM741s en paralelo, en la configuracion de seguidores de voltaje ´
es decir la salida del potenciometro a la terminal no inver- ´ sora de ambos OPAMPs, entonces se conectan como seguidores de voltaje y sus salidas se unen, cada OPAMP puede manejar 20mA, combinados pueden manejar hasta 40mA

### 1.10 Un-Offset de CD

Antes de enviar nuestra senal a nuestro altavoz, tenemos que ˜ asegurarnos de que este oscilando alrededor de 0v, hasta este momento la senal que hemos estado manipulando se encuentra ˜ oscilando alrededor de 2.5v, para arreglar esto tenemos que usar un capacitor grande, como indicamos en el esquematico, ´
utilizamos uno de 220uF para bajar esa senal de su posici ˜ | on´
actual y que pueda ser así reproducida en nuestro altavoz

### 2. Disenõ

### 2.1 Esquematico ´

El diagrama esquematico que se utiliz ´ | o se encuentra en los ´
anexos del documento para no afectar al formato de este reporte
El diseno de nuestro circuito se realiz ˜ | o en Altium de- ´
signer 14, utilizando los estandares de la IPC 2221A y re- ´ glas de diseno apropiadas de OSHPark.com esto para para ˜ en caso poder maquilar el circuito impreso por medio de los archivos GERBER; los componentes se adquirieron por medio de Newark element14 debido a la facilidad de seleccionar los componentes y sus datasheets en línea
Los archivos Extended GERBER, o RS-274X generados fueron los siguientes
1. .DRL Archivo para taladrar
2. .GBL Bottom Layer
3. .GBS Bottom Soldermask
4. .GKO Board Outline
5. .GTL Top Layer
6. .GTO Top Silkscreen
7. .GTS Top Soldermask

para la generacion de la placa de Circuito Impreso (PCB) ´ se enviaron todos los archivos juntos en un archivo comprimido ZIP por medio de internet a OSH Park en estados unidos en donde se procesaron con las siguientes características

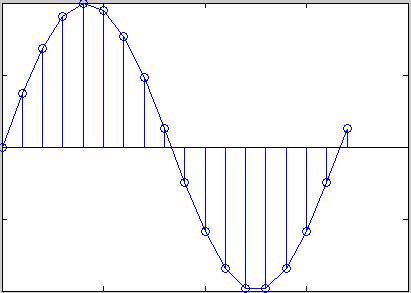
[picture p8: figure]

Figure 4. Senal Analogica o continua ˜

### 2.2 Simulacion en MATLAB ´

Para verificar el proceso de muestreo y Cuantizacion es necesario simular el proceso atravez de MATLAB, este software
nos permite simular, una senal continua (anal ˜ | ogica) y su con- ´
version a se ´ | nal discreta (digital) por medio del proceso de la ˜
teoría de Cuantizacion, tambien nos permite utilizar el orde- ´ nador para generar una muestra de sonido de ambas, la senal ˜ continua y la senal discreta (digital) ˜
Podemos ver en que consiste el proceso de muestreo o ´ cuantificacion de la onda, donde a partir del modelo original ´ intentamos reconstruirla mediante la generacion de puntos ´ sobre su trazo. En la imagen inferior se aprecia como la ´
fidelidad de la reconstruccion depende tambi ´ | en del n ´ | umero ´
de bits utilizado (bitrate).
2.2.1 Simulacion de se ´ | nal continua ˜
A continuacion se muestra el c ´ | odigo requerido para poder ´
graficar una senal anal ˜ | ogica utilizando una frecuencia de ´
muestreo de 8000kHz, es posible cambiar ambos, la frecuencia, y la frecuencia de muestreo, la funcion´ plot graficara nuestra grafica en donde podremos ver y escuchar vía el altavoz de la computadora el sonido analogico esta es una simu- ´
lacion de la se ´ | nal de entrada (sin offset) que entrara en nuestro ˜
microcontrolador
clf
t=0:1:16.66
y=sin(2*pi*0.06*t)
plot(t,y)
hold on
plot(t,y,’ko’)
hold off
n=[0:1:10000]
ftono=440
fm=8000
Tm=1/fm
A=1
y=A*sin(2*pi*ftono*Tm*n)
sound(y,fm)
xlabel(’Tiempo [ms]’)
ylabel(’Tension RMS [v]’)

Tarjeta de audio de procesamiento de voz dígital — 6/9

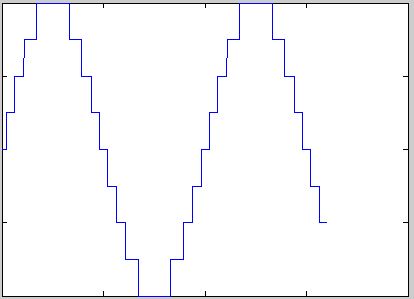
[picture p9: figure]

Figure 5. Senal digital o discreta ˜

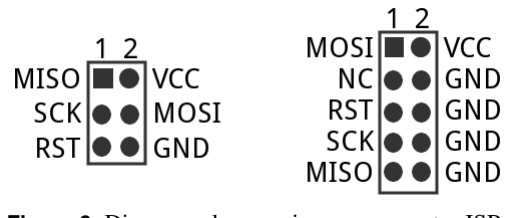
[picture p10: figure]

Figure 6. Diagrama de conexion para conector ISP

title(’Simulacion de conversi ´ | on Analogica Digital’) ´
2.2.2 Simulacion de se ´ | nal discreta ˜
El siguiente codigo nos permite modificar el n ´ | umero de mues- ´
tras, al mismo tiempo de graficar nuestra senal en el tiempo ˜
en forma discreta, este codigo tambi ´ | en nos permite reproducir ´
el sonido que genera esta senal digital en el altavoz de nuestro ˜ computador, es posible variar N de 1 a 16 bits, siendo 16 bits la mejor calidad de audio que el oído humano puede percibir clf
t = 0:1:1600
fm = 1000
Tm=1/fm
ftono = 440
N = 2

2
senial = sin(2*pi*t*ftono*Tm)
y = round(senial*N)/N
plot(round(sin(2*pi*t/1000)*N)/N) sound(round(sin(2*pi*t*ftono*Tm)*N)/N, 1000)

### 2.3 Lista de Materiales

Los componentes se adquirieron por medio de newark element14 esto debido a la escasez de componentes especializa-
dos como las resistencias de precision de 10k 20k y 3k, as ´ | í
como por conveniencia para cumplir los plazos del proyecto, los costos de los componentes fueron los siguientes

### 2.4 Programacion ISP ´

Programacion en el sistema (In-system programming) o ISP , ´ por sus siglas en ingles, es la habilidad de algunos dispositivos ´

Table 1. Tabla de componentes
Cant. | Componente | Costo(USD)
1 | Resistencia 10 | 0.11
1 | Resistencia 8.2k | 0.11
7 | Resistencia 10k | 0.77
9 | Resistencia 20k | 0.99
3 | Resistencia 100k | 0.33
1 | Resistencia 3k | 0.11
2 | Clema para PCB | 2.00
1 | Cristal Oscilador 12Mhz | 1.20
5 | OPAMP LM741 | 4.00
1 | ATMega328P | 2.82
5 | Capacitor 10uF | 0.11
2 | Capacitor 22nF | 0.33
1 | Capacitor 0.01uF | 0.50
1 | Header Male 5x2 | 1.50
2 | Trimpot 50M | 1.50
1 | Bocina 8Ohms | 3.00
1 | Push Button NC | 0.21
1 | Maquilacion PCB | 15.00

logicos programables, microcontroladores y otros circuitos ´
electronicos de ser programados mientras est ´ | an instalados ´
en un sistema completo, en lugar de requerir que el chip sea programado antes de ser instalado dentro del sistema. Para programar nuestro microcontrolador es necesario un programador externo, en nuestro caso nos apoyaremos del arduino dado a su facilidad en costo y accesibilidad, sin embargo debemos disenar nuestra tarjeta para poder utilizar pines ˜ de programacion directamente en el circuito impreso, estos ´ nos permitiran reprogramar el microcontrolador directamente ´ conectado en el PCB, el diseno de nuestro PCB tiene contem- ˜ plado el ruteo de los pines VCC, MISO, MOSI, SCK, CC y
GND, para cumplir este proposito, as ´ | í como los componentes
requeridos para que el microcontrolador pueda funcionar de manera autonoma en nuestro PCB ´
2.5 Codigos de programaci ´ | on en C ´
En los 4 siguientes codigos de programaci ´ | on, se demuestran ´
diversos metodos para leer la se ´ | nal de voz de entrada en el ˜
puerto A0 como un numero entre 0 y 1023 lo almacenan como la variable IncomingAudio, desde aquí, es posible almacenar este valor para un uso posterior, así como realizar operaciones matematicas con el mismo ´
Se utilizo un DAC de 8 bit para poder visualizarlos puntos ´ de informacion que el microcontrolador almacena como la ´ variable IncomingAudio y poder compararla que tan cerca
esta de la se ´ | nal original, podemos calcular la tasa de muestreo ˜
con la siguiente formula
Es posible utilizar esta informacion para almacenar el ´ valor para un uso posterior o incluso para realizar operaciones
matematicas con ´ | el , o hacer cualquier otro tipo de manipu- ´

Tarjeta de audio de procesamiento de voz dígital — 7/9

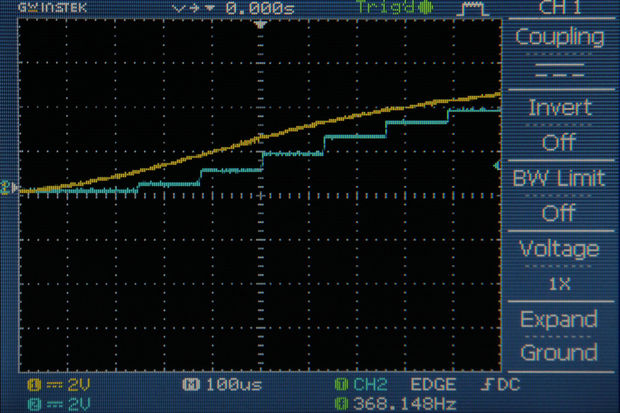
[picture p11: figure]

Figure 7. Salida digital muestreada cada 125uS

lacion con el ´

T muestreo =

1
125uS

=

1
0.000125uS

= 8000Hz (17)

Como se puede ver en la figura, el microcontrolador toma una muestra cada 125uS de A0

### 2.5.1 Muestreo a 8kHz en puerto A0

Por default el comando AnalogRead solo nos proporciona una tasa de muestreo de 8kHz, mas que suficiente para muestrear ´
senales de voz Digital para audio telef ˜ | onico, para poder lo- ´
grar tasas de muestreo mas elevadas es necesario saltarnos la ´ funcion´ AnalogRead, y utilizar la hoja de datos para modificar la tasa de muestreo del ADC int incomingAudio;
void setup()
for (byte i=0;i¡8;i++) pinMode(i,OUTPUT);
void loop()
incomingAudio = analogRead(A0); incomingAudio = (incomingAudio+1)/4 - 1;
if (incomingAudio¡0)
incomingAudio = 0;

### 2.5.2 Muestreo a 8kHz en A0 con salida a DAC de 8 bits

El codigo anterior permite al microcontrolador leer los val- ´ ores a 8kHz sin embargo solo hemos leído la senal no hemos ˜
redirigido a ningun puerto la se ´ | nal digital, para poder visu- ˜
alizarla en el osciloscopio es necesario un DAC R/2R de 8 bit para poder convertir la senal en algo que resemble a una ˜
senal Analogica, este c ˜ | odigo permite redirigir la se ´ | nal del ˜
microcontrolador hacia el puerto B en donde se utilizaran sus 7 canales para conectar nuestro DAC
int incomingAudio;
void setup()
| for (byte i=0;i¡8;i++) pinMode(i,OUTPUT);

void loop()
| incomingAudio = analogRead(A0); incomingAudio = (incomingAudio+1)/4 - 1; if (incomingAudio¡0)

incomingAudio = 0;
| PORTD = incomingAudio;

### 2.5.3 Muestreo a 38.5kHz por el puerto A0

Es posible ordenar al microcontrolador omitir las otras en-
tradas analogicas con el prop ´ | osito de obligar una medici ´ | on´
constante y en tiempo real del pin A0, de esta manera mientras el microcontrolador entra en un loop infinito, el microcontro-
lador se mantendra actualizando la variable llamada ´ | | ADCH
con nuevos valores de A0 a un ritmo de 38.5kHz (Una muestra cada 26uS), para esto es necesario reducir la resolucion de las ´ medidas analogicas un poco, para obtener una mayor tasas de ´ muestreo
Utilizando la hoja de datos, del microcontrolador podemos modificar el conversor analogico digital de la entrada Analog- ´ ica A0, en el ADCH directamente (En el primer codigo solo ´ leímos los 8 bits mas significativos, del ADC de 10 bits, para ´ trabajar de la manera mas r ´ apida posible y ahorrar tiempo a la ´ hora de programar) podemos colocar el contador del ADC a 500KHz debido a que el ADC toma 13 ciclos en leer el nuevo valor analogico ´

T muestreo =

500kHz
13
= 38.5kHz | (18)

Valor que nos acerca a los 40kHz (Valor estandar de ´ muestreo musical) sin inducir ninguna clase de ruido adicional, esto permite al microcontrolador tomar muestras cada

T muestreo =

13
500000Hz
= 26uS | (19)

El codigo para lograr esta velocidad de lectura en el puerto ´ A0 es el siguiente
int incomingAudio;
void setup()
ADCSRA = 0;
ADCSRB = 0;
ADMUX —= (1 ¡¡ REFS0);
ADMUX —= (1 ¡¡ ADLAR);
ADCSRA —= (1 ¡¡ ADPS2) — (1 ¡¡ ADPS0); ADCSRA —= (1 ¡¡ ADATE);
ADCSRA —= (1 ¡¡ ADEN);
ADCSRA —= (1 ¡¡ ADSC);
void loop()
incomingAudio = ADCH;

### 2.5.4 Muestreo a 38.5kHz en puerto A0 con salida a DAC

de 8 bits
void setup()
for (byte i=0;i¡8;i++)
pinMode(i,OUTPUT);
ADCSRA = 0;
ADCSRB = 0;
ADMUX —= (1 ¡¡ REFS0);
ADMUX —= (1 ¡¡ ADLAR);
ADCSRA —= (1 ¡¡ ADPS2) — (1 ¡¡ ADPS0); ADCSRA —= (1 ¡¡ ADATE);
ADCSRA —= (1 ¡¡ ADEN);

Tarjeta de audio de procesamiento de voz dígital — 8/9

ADCSRA —= (1 ¡¡ ADSC);
void loop()
PORTD = ADCH;

### 2.6 Circuito Impreso

Inicialmente el circuito se armo en protoboard para verificar ´ su funcionamiento, al verificar su correcto funcionamiento
se realizo el esquem ´ | atico en Altium Designer para poder ´
generar una version imprimible del mismo la cual se pas ´ | o a ´
PCB y nuevamente se probo, al verificar su funcionamiento ´ y corregir la posicion de los componentes, se generaron los ´ archivos GERBER requeridos para su maquilacion, esto nos ´ permitio enviar a maquilar nuestro circuito ´

### 3. Conclusiones y Observaciones

Este arreglo no da la mejor calidad de audio para musica, ´ sin embargo es mas que suficiente para voz, es posible uti- ´ lizar Circuitos integrados ADC de 16bit y 24bit con estos es posible obtener una mejor calidad de audio, algunos modelos específicos incluso pueden proporcionar salidas estereo ´ sin embargo habría que recurrir a Circuitos integrados mas´ avanzados y especializados
Se utilizaron LM741 debido a que se tienen de sobra de todas las practicas a lo largo de la carrera, se pudo utilizar em- ´
paquetados mas peque ´ | nos que contienen 4, LM741 integrados ˜
sin embargo se opto por utilizar los componentes existentes ´ La calidad de sonido de salida es baja debido al proceso de conversion del ADC de 8 bits de resistencias, es probable ´ incrementar la calidad del sonido utilizando un ADC de 16 bits sin embargo se tendría que encontrar un microcontrolador capaz de manejar 16 puertos de salida simultaneamente es de ´ un audio analogico de 8 bits, por lo que canciones con una ´ mejor calidad de audio
El led azul indicador SMD de 10v se quemo durante las ´ pruebas iniciales, esto se debio al c ´ alculo de la resistencia ´ limitadora de corriente fue ”demasiado exacto” por lo que la tolerancia paso a jugar en nuestra contra, el led funciono aproximadamente 30 minutos antes de quemarse, se estima que la corriente que paso por el fe de 21mA cuando la corriente maxima soportada por el mismo era de 20mA, este led ´ ya fue reemplazado en la tarjeta final
Se tuvieron distintos problemas de distintos tipos de esta magnitud debido a que se tuvo que llevar un proceso de com-
probacion de teor ´ | ía, verificacion en laboratorio, repetidas ´
veces, incluso se tuvo que descartar un primer circuito de una
sola cara, que se llego a imprimir soldar, esta ´ | nar y probar ˜
de manera casera, esto nos llevo a tener la problem ´ | atica de ´
tener que reparar distintas pistas que o no se pasaron bien a la placa o se arrancaron en el proceso de estanado, finalmente ˜ se comprobo que lo ideal es pasar de la protoboard al PCB ´
siempre y cuando se tenga muy en claro como se deber ´ | a pasar ´
de protoboard a PCB, así como procurar siempre un disenõ modular con puntos de prueba incluidos en el PCB para poder
tener una maniobrabilidad incluso despues de que el PCB est ´ | é
terminado

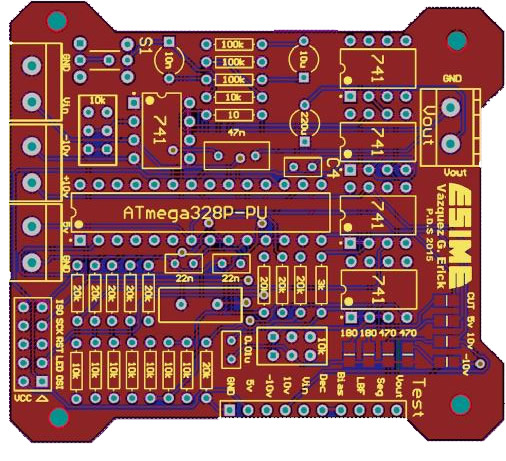
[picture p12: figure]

Figure 8. PCB Layout doble capa enviado a Maquilacion

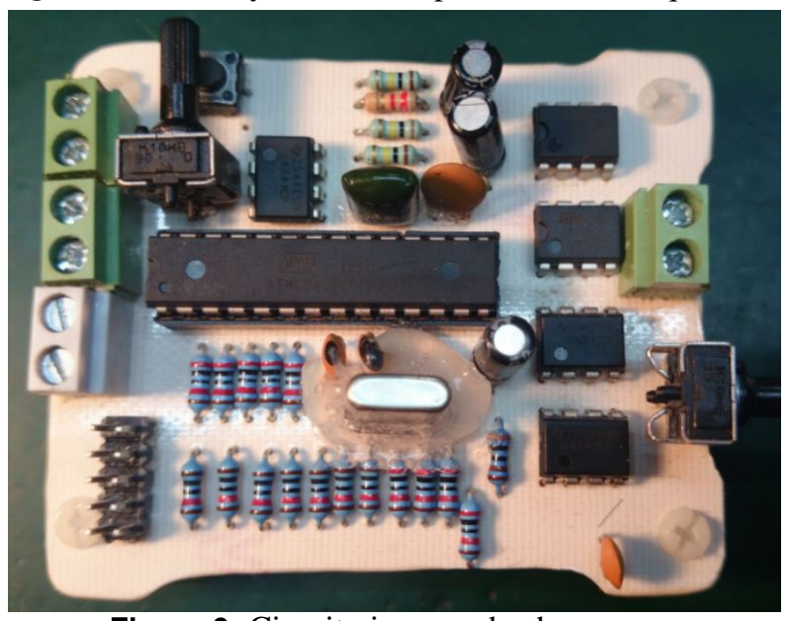
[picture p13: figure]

Figure 9. Circuito impreso hecho en casa

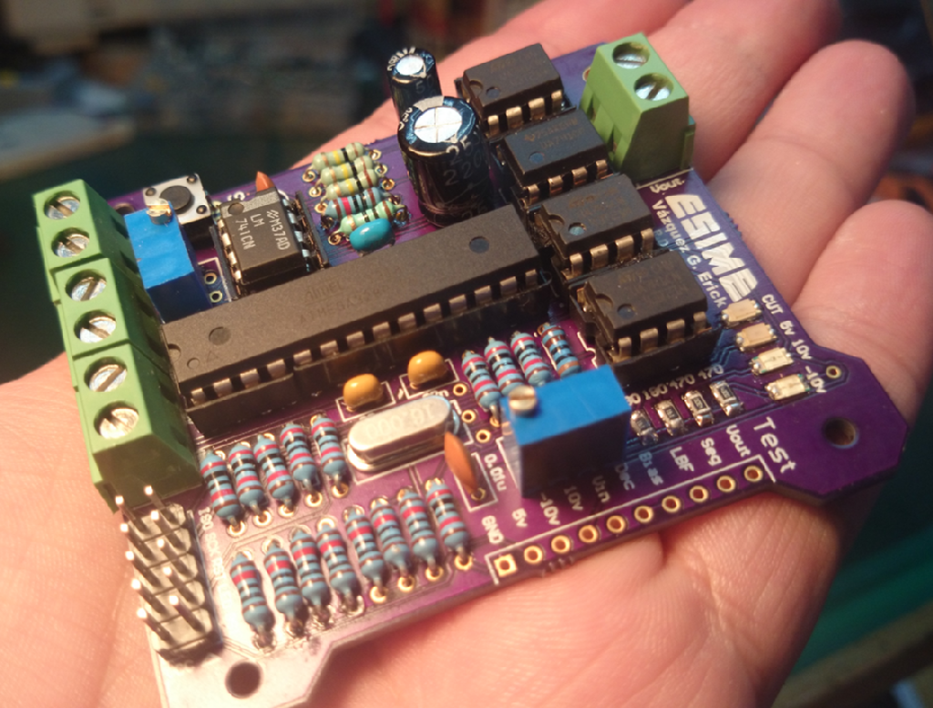
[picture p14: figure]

Figure 10. Tarjeta maquilada en OSHPark.com

Tarjeta de audio de procesamiento de voz dígital — 9/9

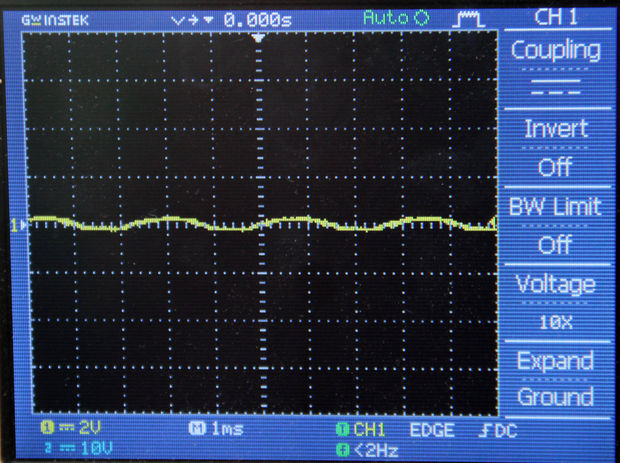
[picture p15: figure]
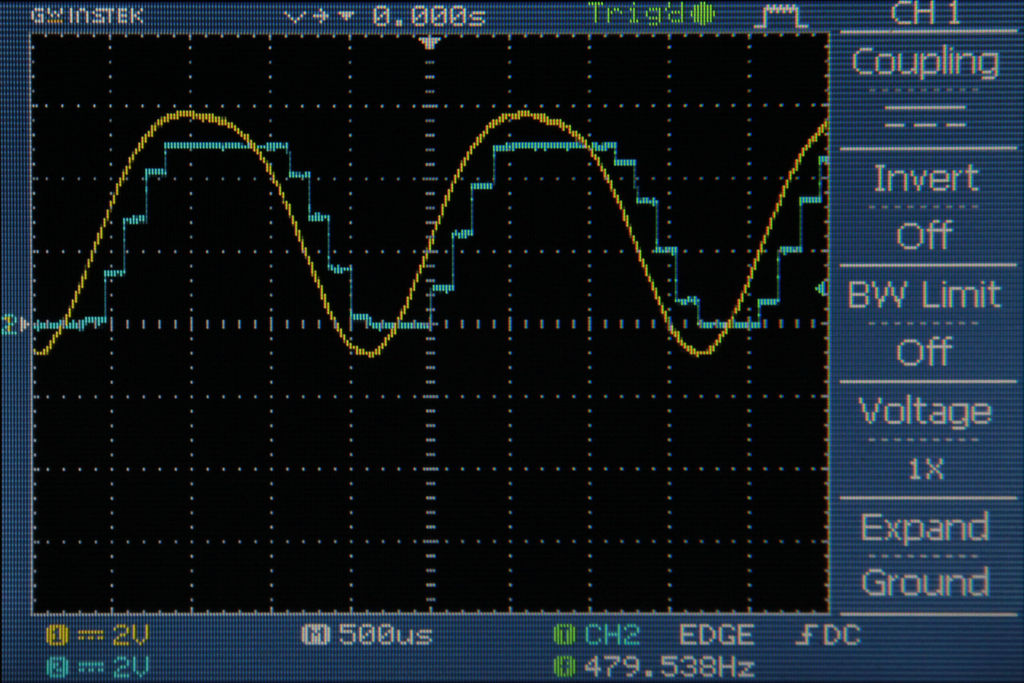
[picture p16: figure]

Figure 11. Senal de Salida de un transductor ˜

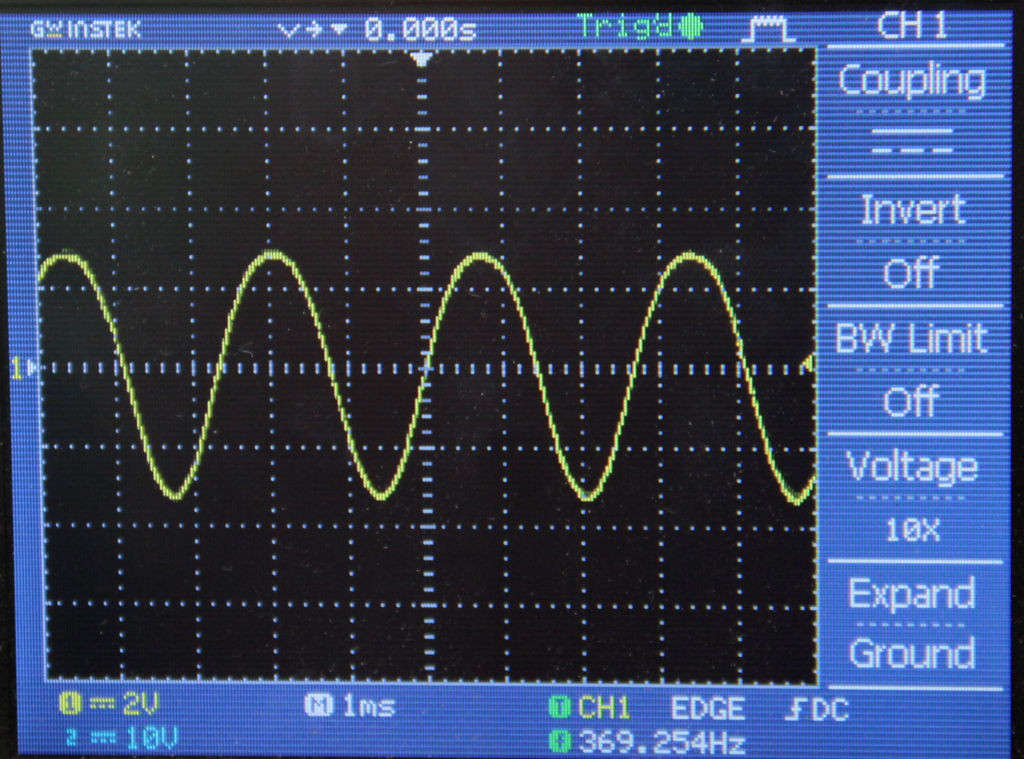
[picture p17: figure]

Figure 12. Senal anal ˜ | ogica amplificada ´
Aunque nosotros oímos la musica como onda anal ´ | ogica (la ´
misma que hace vibrar nuestro tímpano), cuando esta llega al ´
cerebro la informacion es transformada en pulsos el ´ | ectricosEs ´
decir, que nuestro propio cerebro realiza un proceso de “digi-
talizacion” del sonido transform ´ | andolo en quantos de infor- ´
macion que puedan ser transmitidos por la corteza cerebral y ´ otras partes del cerebro interno. Por tanto, en el proceso de
escucha de cualquier cancion existen tanto partes anal ´ | ogicas ´
como digitales que se van alternando continuamente incluso dentro de nosotros mismos.

### 4. Bibliografía y referencias

-Practical Electronics for inventors, Feb 2013, Paul Scherz htt p : //electronics.stackexchange.com/
-Analog Sampling Basics
htt p : //www.ni.com/white− paper/3016/en/
-Analog Input Subsystem
htt p : //www.mathworks.com/hel p/daq/analog−input− subsystem.html
-PCB Design Tutorial

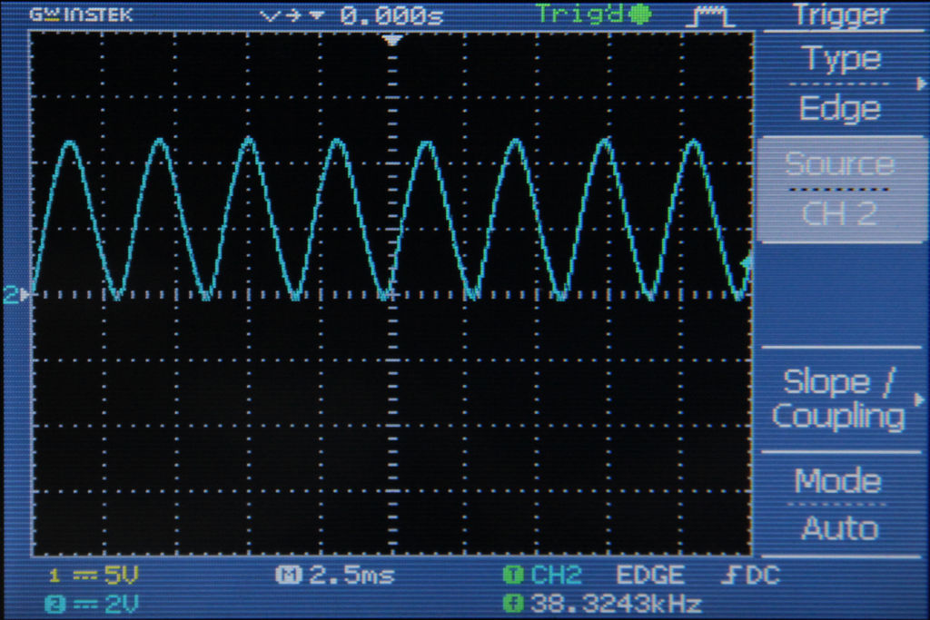
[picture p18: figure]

alternatezone.com/electronics/ files/PCBDesignTutorialRevA.pd f -Basic Circuits - Bypass Capacitors

Figure 13. Senal Amplificada con offset de DC ˜

Figure 14. Senal Acondicionada vs se ˜ | nal de salida ˜

htt p : //www.seattlerobotics.org/encoder/ jun97/basics.html -¿Se puede tocar el sonido? Sonido analogico versus ´ digital blogs.heraldo.es/ciencia/?p = 2845

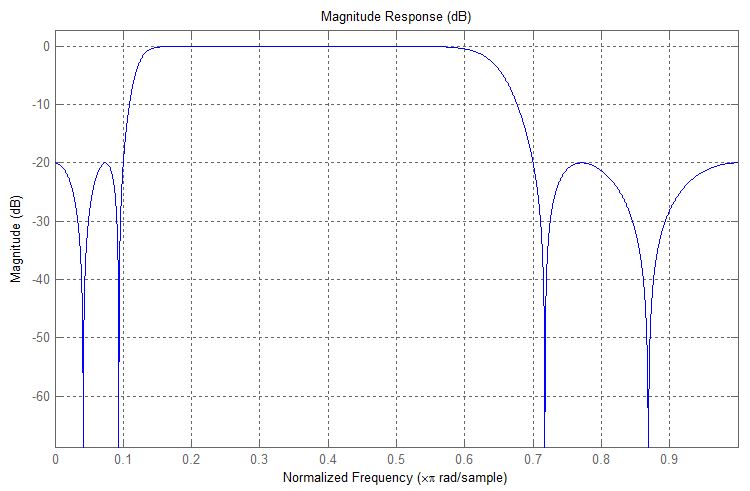
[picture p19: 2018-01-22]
img/m1.JPG

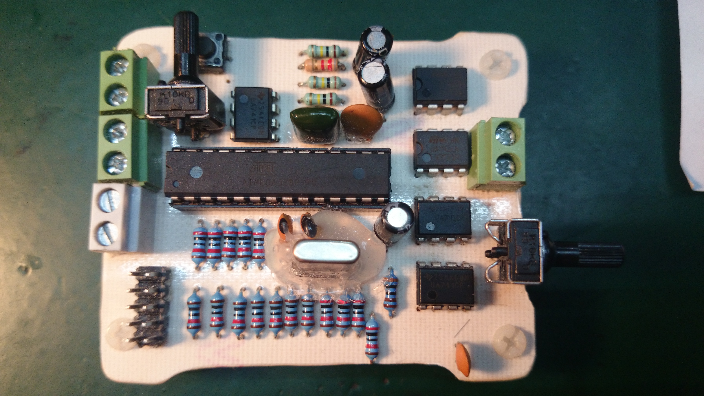
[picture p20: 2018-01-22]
img/2014-11-20 16.28.25.jpg

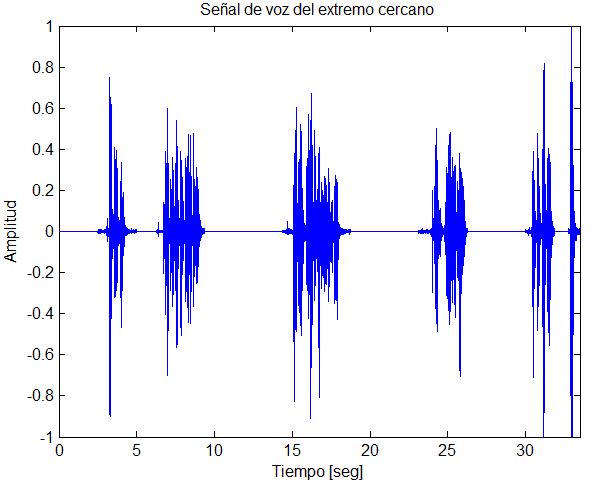
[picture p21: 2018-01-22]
img/m3.JPG

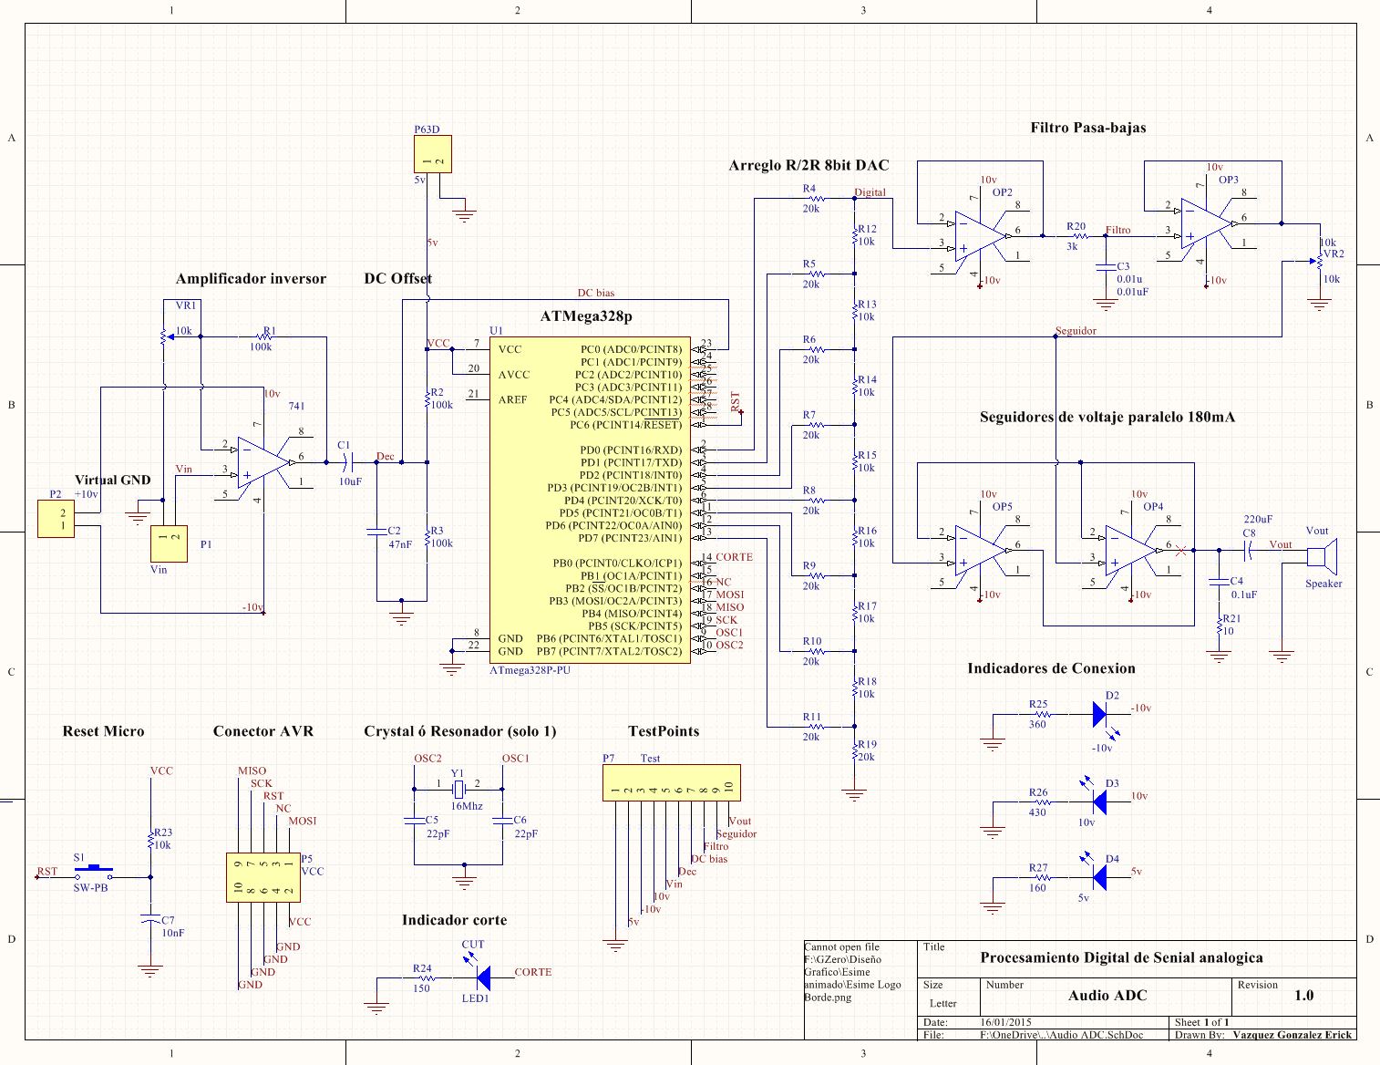
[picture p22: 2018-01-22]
img/MMM.JPG

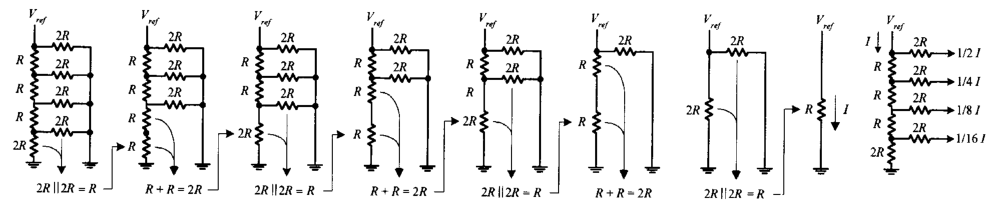
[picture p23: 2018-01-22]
img/r2r.png

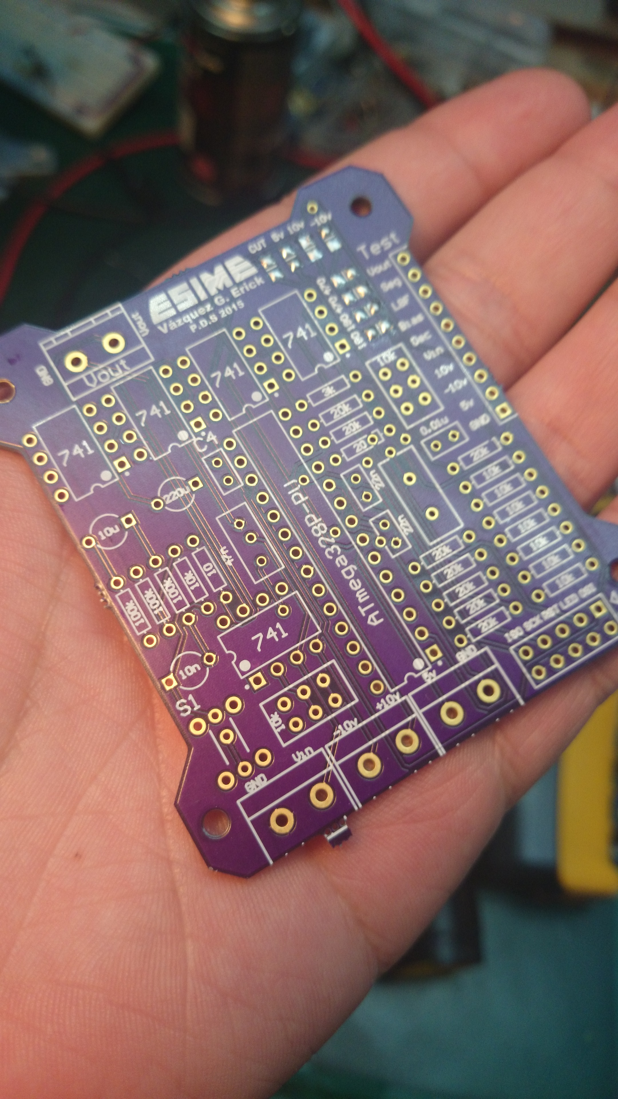
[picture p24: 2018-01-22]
img/IMG-20141219-WA0000.jpg

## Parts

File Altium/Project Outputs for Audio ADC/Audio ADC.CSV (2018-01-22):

Bill of Material for
On 23/11/2014 at 05:59:01 p.m.
Comment | Pattern | Quantity | Components
+10v | cONECTOR | 1 | P2 | Header, 2-Pin
0.01u | RAD-0.1 | 1 | C3 | Capacitor
10 | AXIAL-0.3 | 1 | R21 | Resistor
100k | AXIAL-0.3 | 3 | R1, R2, R3 | Resistor
10k | AXIAL-0.3 | 8 | R12, R13, R14, R15, R16, R17, R18, R23 | Resistor
10k | TPParado | 2 | VR1, VR2 | Potentiometer
10n | CAPR5-4X5 | 1 | C7 | Capacitor
10u | CAPR5-4X5 | 1 | C1 | Capacitor
10v | 6-0805_M | 1 | D3 | Typical RED GaAs LED
-10v | 6-0805_M | 1 | D2 | Typical RED GaAs LED
150 | 6-0805_M | 1 | R24 | Resistor
160 | 6-0805_M | 1 | R27 | Resistor
16Mhz | Crystal | 1 | Y1 | Crystal Oscillator
20k | AXIAL-0.3 | 9 | R4, R5, R6, R7, R8, R9, R10, R11, R19 | Resistor
220u | CAPR5-4X5 | 1 | C8 | Capacitor
22n | RAD-0.1 | 2 | C5, C6 | Capacitor
360 | 6-0805_M | 1 | R25 | Resistor
3k | AXIAL-0.3 | 1 | R20 | Resistor
430 | 6-0805_M | 1 | R26 | Resistor
5v | 6-0805_M | 1 | D4 | Typical RED GaAs LED
5v | cONECTOR | 1 | P63D | Header, 2-Pin
741 | DIP-8 | 5 | OP1, OP2, OP3, OP4, OP5 | FET Operational Amplifier
ATmega328P-PU | 28P3 | 1 | U1 | 8-bit AVR Microcontroller, 32KB Flash, 1KB EEPROM, 2KB SRAM, 28-pin PDIP, Industrial Grade (-40°C to 85°C)
Cap | RAD-0.1 | 1 | C4 | Capacitor
Cap | RAD-0.2 | 1 | C2 | Capacitor
LED1 | 6-0805_M | 1 | CUT | Typical RED GaAs LED
Speaker | cONECTOR | 1 | Vout | Loudspeaker
SW-PB | PBUniversal | 1 | S1 | Switch
Test | HDR1X10 | 1 | P7 | Header, 10-Pin
VCC | HDR2X5 | 1 | P5 | Header, 5-Pin, Dual row
Vin | cONECTOR | 1 | P1 | Header, 2-Pin

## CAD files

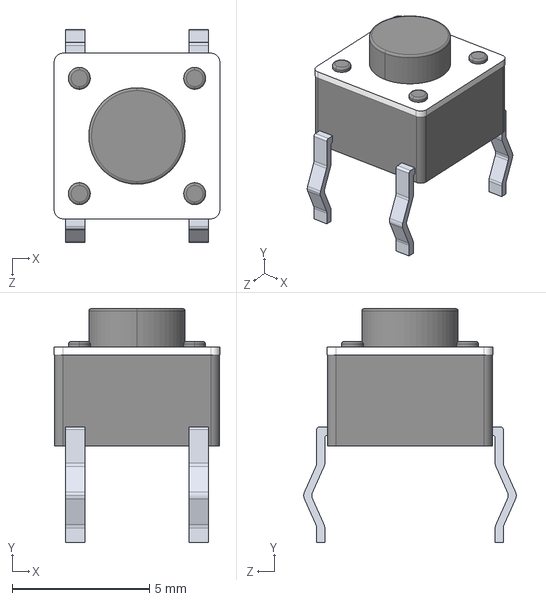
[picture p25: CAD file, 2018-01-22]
Altium/User Library-Tactile switch 6x6x5mm.step
6.03 x 8.52 x 7.74 mm

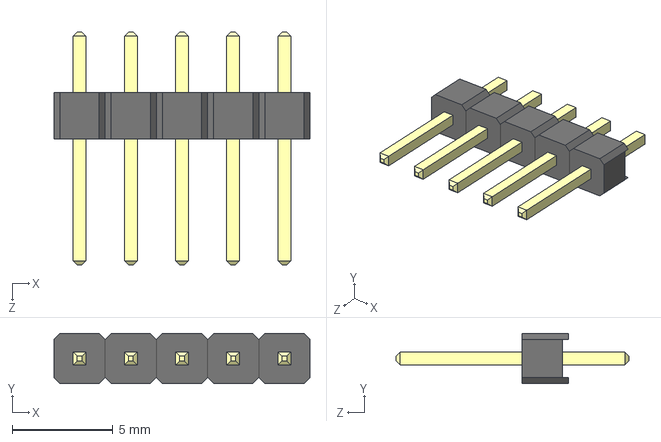
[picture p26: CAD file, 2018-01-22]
Altium/User Library-Header_Male_5Pin.STEP
12.7 x 2.49 x 11.5 mm
User Library-Header_Male_5Pin_PinArray
User Library-Header_Male_5Pin_BodyArray

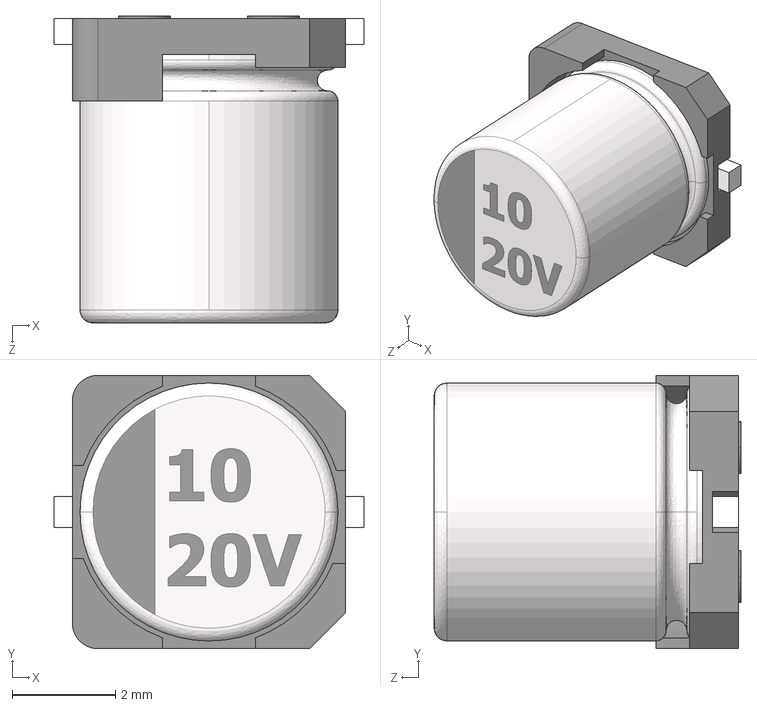
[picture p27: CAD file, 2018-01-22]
Altium/10Uf METAL.step
6.00 x 5.30 x 5.95 mm

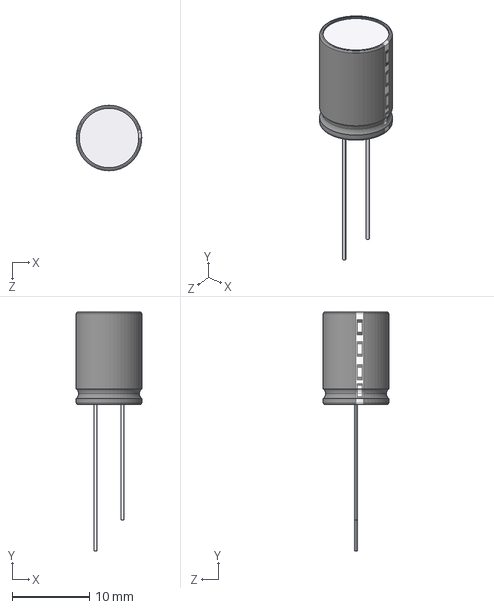
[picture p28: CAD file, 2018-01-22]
Altium/User Library-GXE10VB221MX12LL.step
8.50 x 31.0 x 8.50 mm

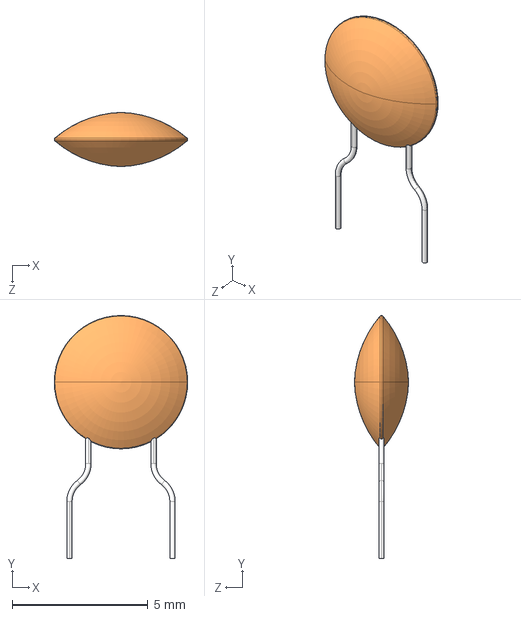
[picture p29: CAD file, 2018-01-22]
Altium/104.step
4.92 x 8.96 x 2.00 mm

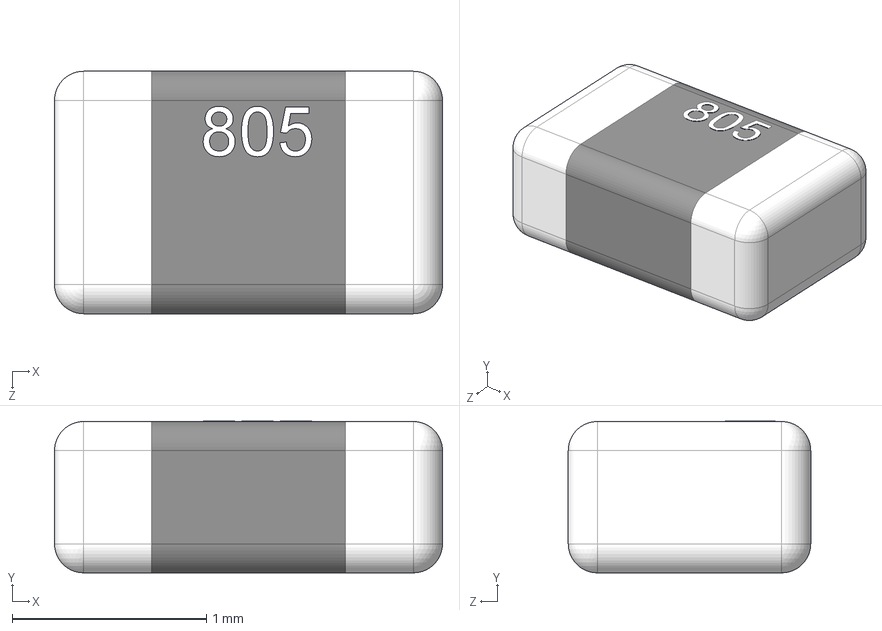
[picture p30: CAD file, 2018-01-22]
Altium/User Library-0805 SMD Resistor.step
2.00 x 0.782 x 1.25 mm

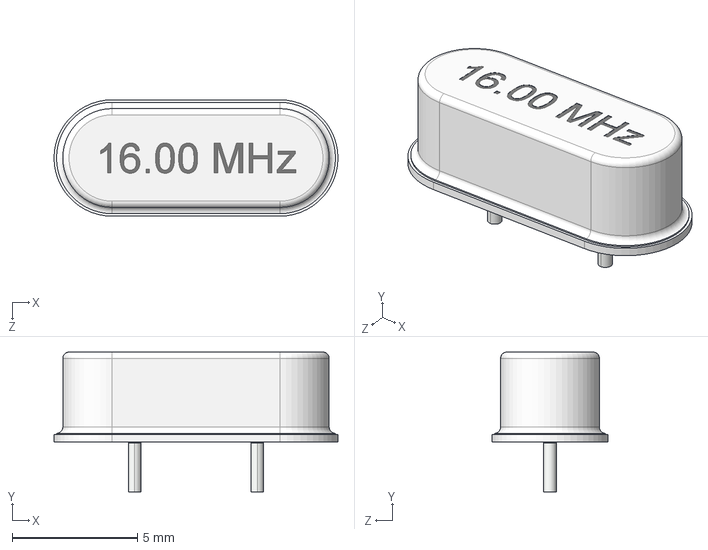
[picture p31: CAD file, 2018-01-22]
Altium/User Library-HC-49_LT_THT_16MHz.step
11.3 x 5.59 x 4.65 mm

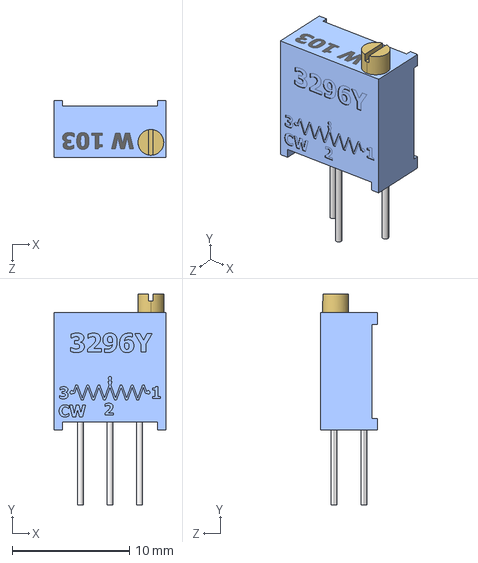
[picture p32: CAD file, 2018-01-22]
Altium/User Library-Trimming Potentiometer Vertical 3296Y 103 - 10k.STEP
9.53 x 18.0 x 4.83 mm

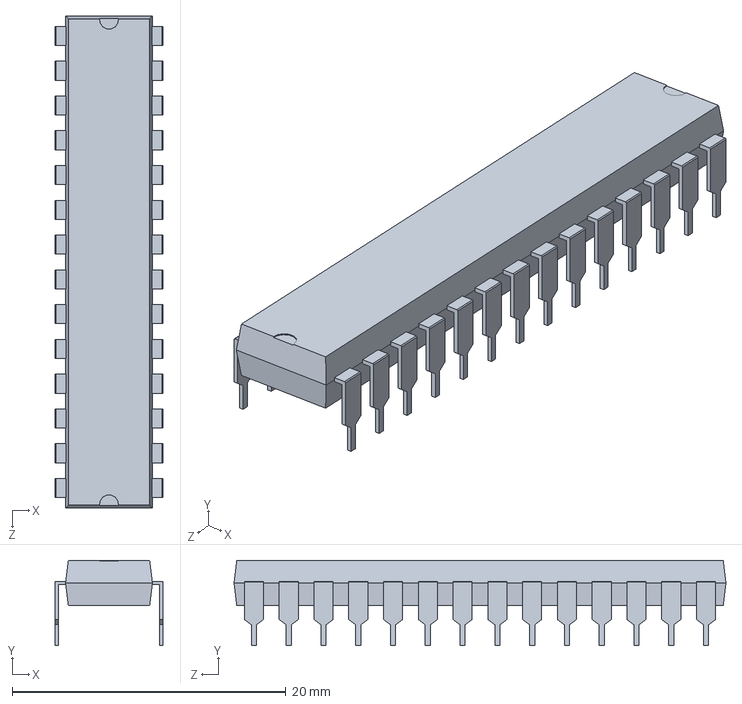
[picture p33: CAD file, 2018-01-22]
Altium/Dip28.SLDPRT
7.87 x 6.22 x 35.9 mm

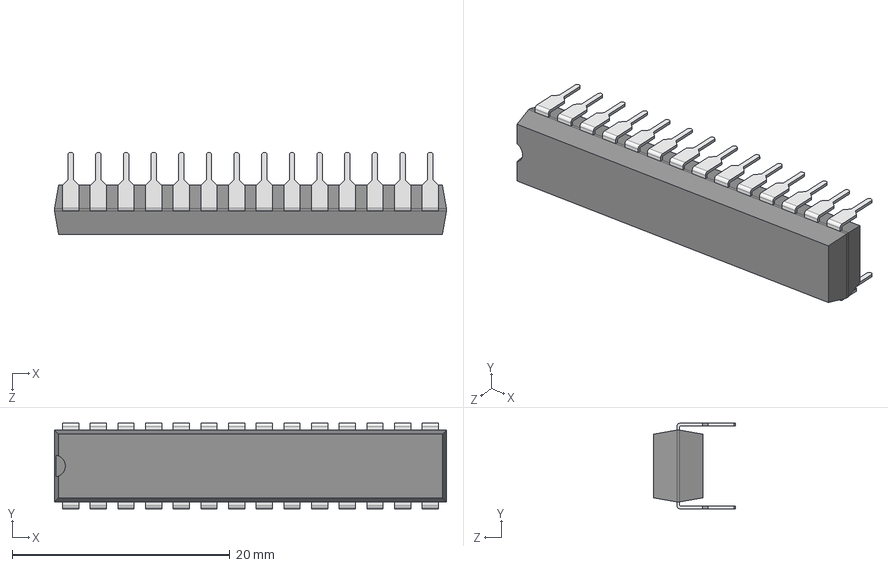
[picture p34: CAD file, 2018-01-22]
Altium/User Library-DIP28-300.step
36.0 x 7.87 x 7.57 mm

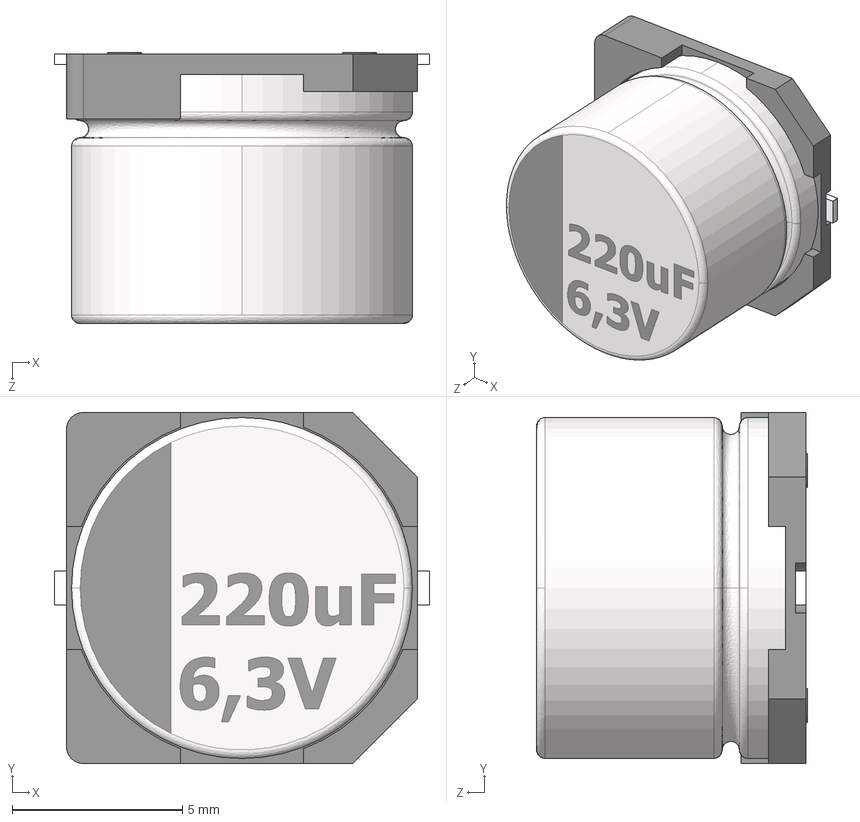
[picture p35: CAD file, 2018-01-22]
Altium/220.step
11.0 x 10.3 x 7.95 mm

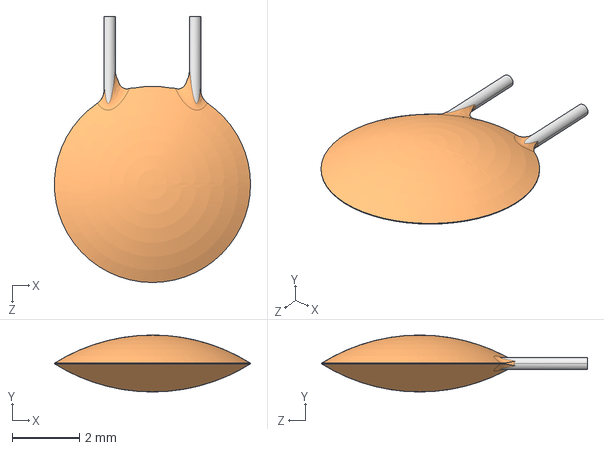
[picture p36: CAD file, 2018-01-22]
Altium/SW3dPS-Cap 100n.STEP
5.84 x 1.70 x 7.92 mm

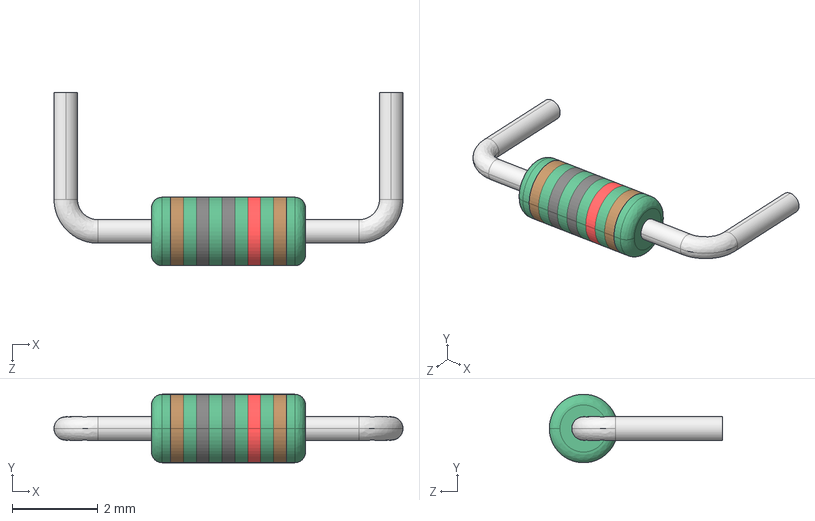
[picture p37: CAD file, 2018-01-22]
Altium/User Library-CCF50__10K0_b7.STEP
8.15 x 1.60 x 4.05 mm
User Library-CCF50__10K0_b7_BODY
User Library-CCF50__10K0_b7_Ring1_10K0
User Library-CCF50__10K0_b7_WIRE_BEND x 2

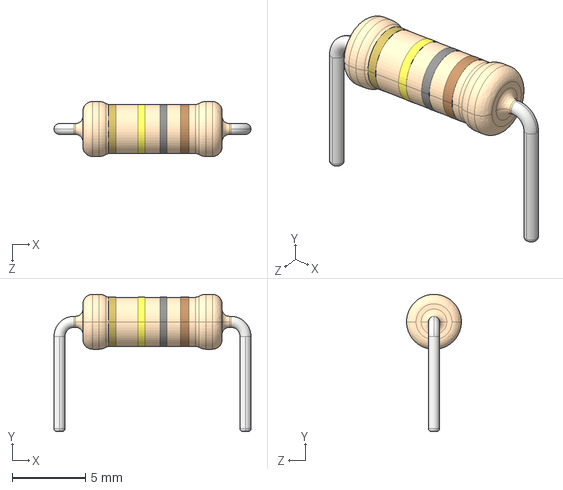
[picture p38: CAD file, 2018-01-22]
Altium/User Library-Res50-Axial 0_5W-100K.step
13.4 x 9.38 x 3.75 mm

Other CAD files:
Altium/User Library-LED SMD0805.step
Altium/User Library-Bourns 3362P.step
Altium/User Library-Cap12_5x25.STEP
Altium/47n.step
Altium/CircuitWorks-REDLED.step
Altium/Terminal Block.stp
Altium/User Library-DIP8test.STEP
